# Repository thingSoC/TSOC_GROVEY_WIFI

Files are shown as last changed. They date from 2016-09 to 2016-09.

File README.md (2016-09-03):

# TSOC-GROVEY_WIFI

**TSOC-GROVEY_WIFI** is a Wi-Fi Embedded Module, **thingSoC Reference Design.** 

**thingSoC Reference Designs** are example thingSoC implementations that implement
various reference and testing circuits for demonstrating the use of the thingSoC libraries.
These reference designs are complete designs and can also serve as starting templates for users to customize.

**TSOC-GROVEY_WIFI** includes an ESP8266-07/12E format Wi-Fi module, in a thingSoC compatible pinout.

---------------------------------------

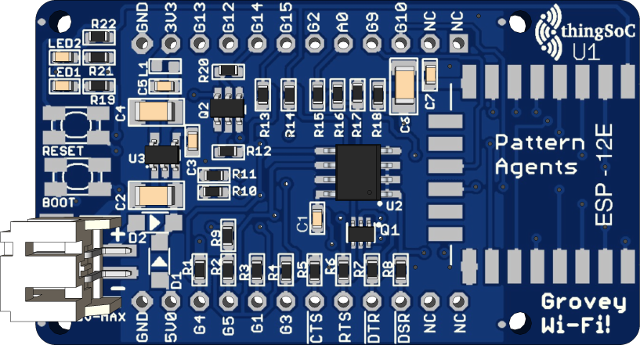
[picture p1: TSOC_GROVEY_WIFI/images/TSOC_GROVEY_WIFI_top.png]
thingSoC TSOC-GROVEY_WIFI
[  
*TSOC-GROVEY_WIFI*](https://github.com/thingSoC/thingSoC/tree/master/examples/eagle6/TSOC-GROVEY_WIFI)

* [Supported by the Arduino IDE](https://www.arduino.cc/) 
* Wi-Fi and OTA (Over the Air) Program Upgrade/Download
* thingSoC Compliant Module
* [Mikrobus Compatible Module](http://www.mikroe.com/mikrobus/) 
* ESP8266 Wi-Fi Module 802.11 b/g/n
* +19.5dBm output power in 802.11b mode
* Wi-Fi Direct (P2P), soft-AP
* Integrated TCP/IP protocol stack
* Internal Antenna and U.FL external Antenna Support

---------------------------------------

## Documentation Index <a name="documentation_index"/>

For ESP8266 Documentation (esp. toolchain info) see [NurdSpace](https://nurdspace.nl/ESP8266)

[thingSoC Organization Website](http://thingSoC.github.io)

[thingSoC FAQ - Frequently Asked Questions](http://thingsoc.github.io/support/faq.html)

---------------------------------------

[  
*thingSoC*](http://thingsoc.github.io)

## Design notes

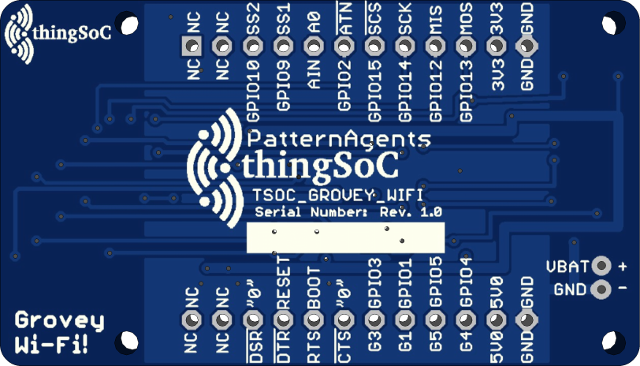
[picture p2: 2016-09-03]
TSOC_GROVEY_WIFI/images/TSOC_GROVEY_WIFI_bot.png

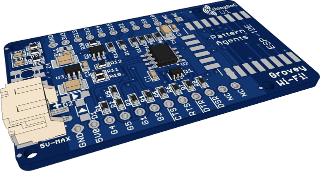
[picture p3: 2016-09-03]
TSOC_GROVEY_WIFI/images/TSOC_GROVEY_WIFI_model.png

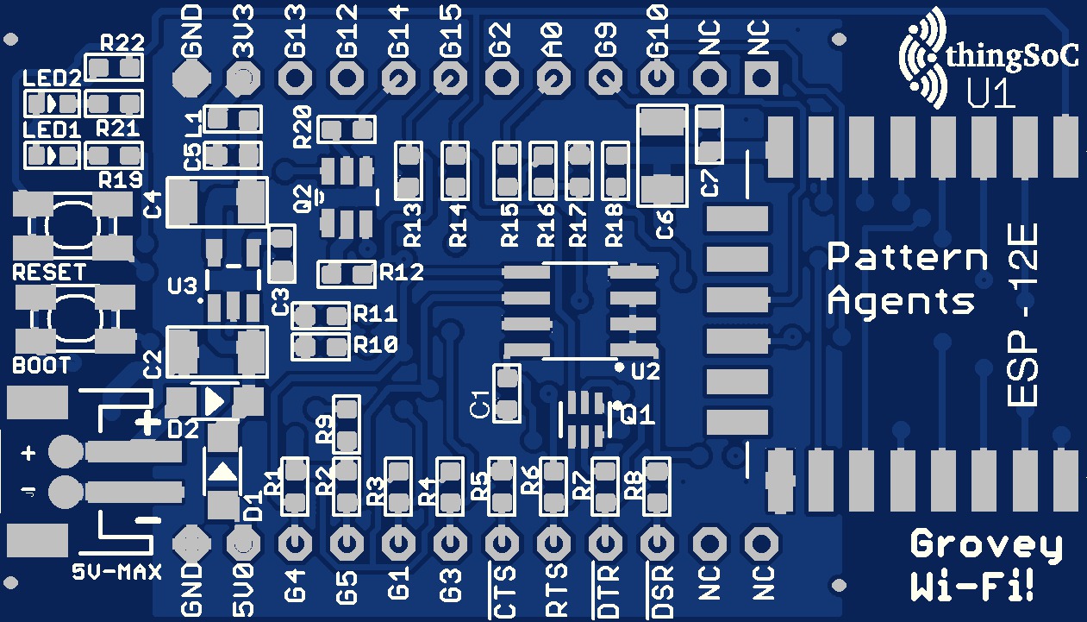
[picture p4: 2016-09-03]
TSOC_GROVEY_WIFI/eagleUp/eagleUp_TSOC_GROVEY_WIFI_board_top.jpg

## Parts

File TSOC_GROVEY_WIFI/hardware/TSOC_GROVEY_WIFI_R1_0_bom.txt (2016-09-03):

Partlist exported from U:/PatternAgents/eagle/TSOC_Modules/TSOC_GROVEY_WIFI/TSOC_GROVEY_WIFI/TSOC_GROVEY_WIFI.sch at 8/28/2016 3:01:39 PM

Qty Value             Device                                 Package               Parts                          Description                          
1                     ESP12ESMD                              ESP12E-SMD            U1                             ESP12E Module                        
1                     JST_2MM_MALE                           JST-2-SMD             J1                             Mates to single-cell LiPo batteries. 
1                     M02-JST-2-PTH-NO_SILK                  JST-2-PTH-NS          J1P                            Standard 2-pin 0.1" header. Use with 
3   100K              SMD-RES-100K-1%-1/10W(0603)            R0603                 R15, R16, R17                  301010196                            
2   100K 1/10W        SMD-RES-100K-5%-1/10W(0603)            R0603                 R5, R8                         301010089                            
3   100nf             CERAMIC-100NF-50V-10%-X7R(0603)        C0603                 C1, C5, C7                     302010138                            
7   10K               SMD-RES-10K-1%-1/10W(0603)             R0603                 R6, R7, R9, R13, R14, R18, R22 301010299                            
3   10uf              CERAMIC-10UF-25V-10%-X5R(1206)         C1206                 C2, C4, C6                     302010181                            
4   1K 1/10W          SMD-RES-1K-5%-1/10W(0603)              R0603                 R10, R11, R19, R21             301010291                            
6   2.2K              SMD-RES-2.2K-5%-1/10W(0603)            R0603                 R1, R2, R3, R4, R12, R20       301010124                            
2   20V-1A            SMD-DIODE-SCHOTTKY-20V-1A(SOD-123)     SOD-123               D1, D2                         304020034                            
1   470pF             CERAMIC-100NF-50V-10%-X7R(0603)        C0603                 C3                             302010138                            
2   DHT-4235A         SMD-BUTTON-TOP-DHT-4235A(4P-4.2X3.2MM) SW4-SMD-4.2X3.2X2.5MM BOOT, RESET                    311020045                            
1   DNP               SMD-FERRITE-CHIP-120-OHM-500MA(0603)   L0603                 L1                             303030001                            
1   FDG1024NZ         FDG1024NZ                              SOT95P280X110-6N      Q2                             FDG1024NZ                            
4   FIDUCIALUFIDUCIAL FIDUCIALUFIDUCIAL                      MICRO-FIDUCIAL        FID1, FID2, FID3, FID4         Fiducial Alignment Points            
1   FM24W256-G        FM24W256-G                             SO08                  U2                             I2C FRAM FM24W256                    
1   GREEN-0603        SMD-LED-CLEAR-GREEN(0603)              LED-0603              LED1                           304090043                            
1   MIC5219 3.3V      V_REG_MIC52193.3V                      SOT23-5               U3                             V_REG MIC5219                        
1   MMBT2222A         MMDT3904                               SOT363                Q1                             Dual NPN transistor                  
1   RED-0603          LED-SMD-RED-DIFFUSED(0603)             LED-0603              LED2                           304090042                            
1   TSOC-24-BB        TSOC-24-BB                             TSOC-BB-S24           TSOC                           thingSoC Twenty-Four(24) Pin Socket  
4   TSOC-LOGO-MED     TSOC-LOGO-MED                          TSOC-LOGO-MED         $$U$1, $$U$2, U$101, U$102     thingSoC Logo                        
1   TSOC-PCB-PLUS     TSOC-PCB-PLUS                          TSOC-BB-BRD-PLUS-DIM  PCB                            thingSoC PCB Outlines

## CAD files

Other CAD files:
TSOC_GROVEY_WIFI/eagleUp/TSOC_GROVEY_WIFI.skp

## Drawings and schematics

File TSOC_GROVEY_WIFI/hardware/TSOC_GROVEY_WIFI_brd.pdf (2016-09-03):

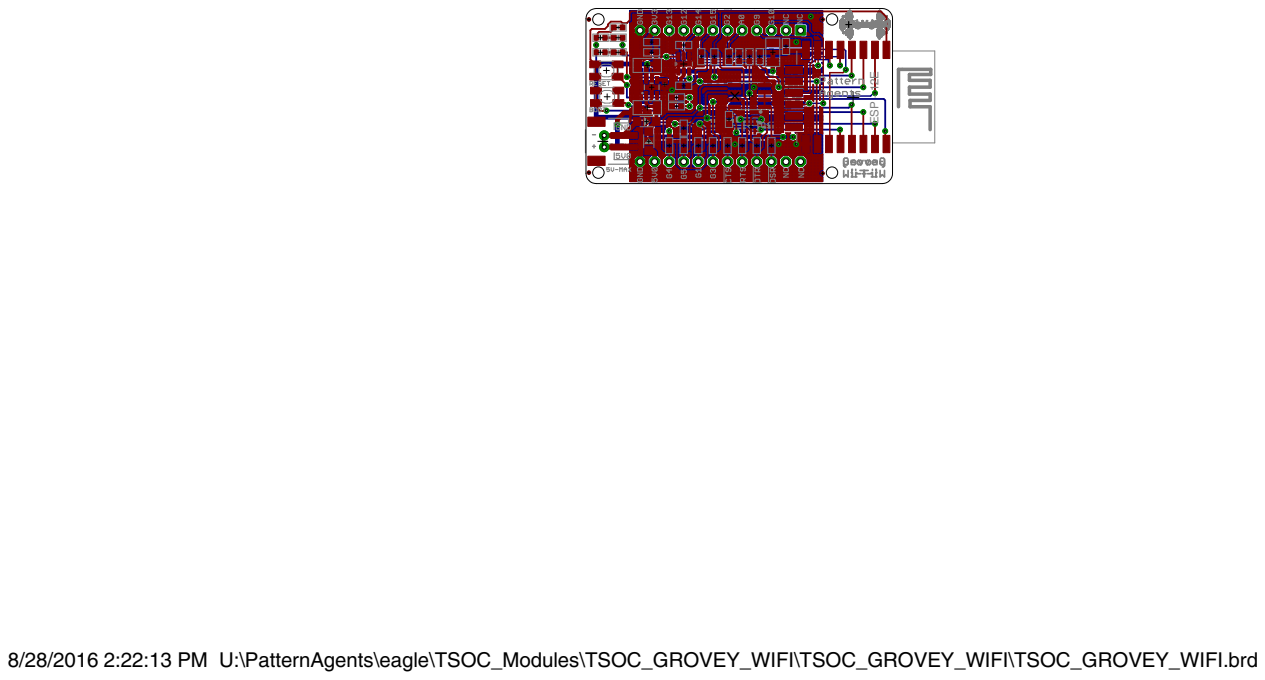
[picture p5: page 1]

8/28/2016 2:22:13 PM U:\PatternAgents\eagle\TSOC_Modules\TSOC_GROVEY_WIFI\TSOC_GROVEY_WIFI\TSOC_GROVEY_WIFI.brd

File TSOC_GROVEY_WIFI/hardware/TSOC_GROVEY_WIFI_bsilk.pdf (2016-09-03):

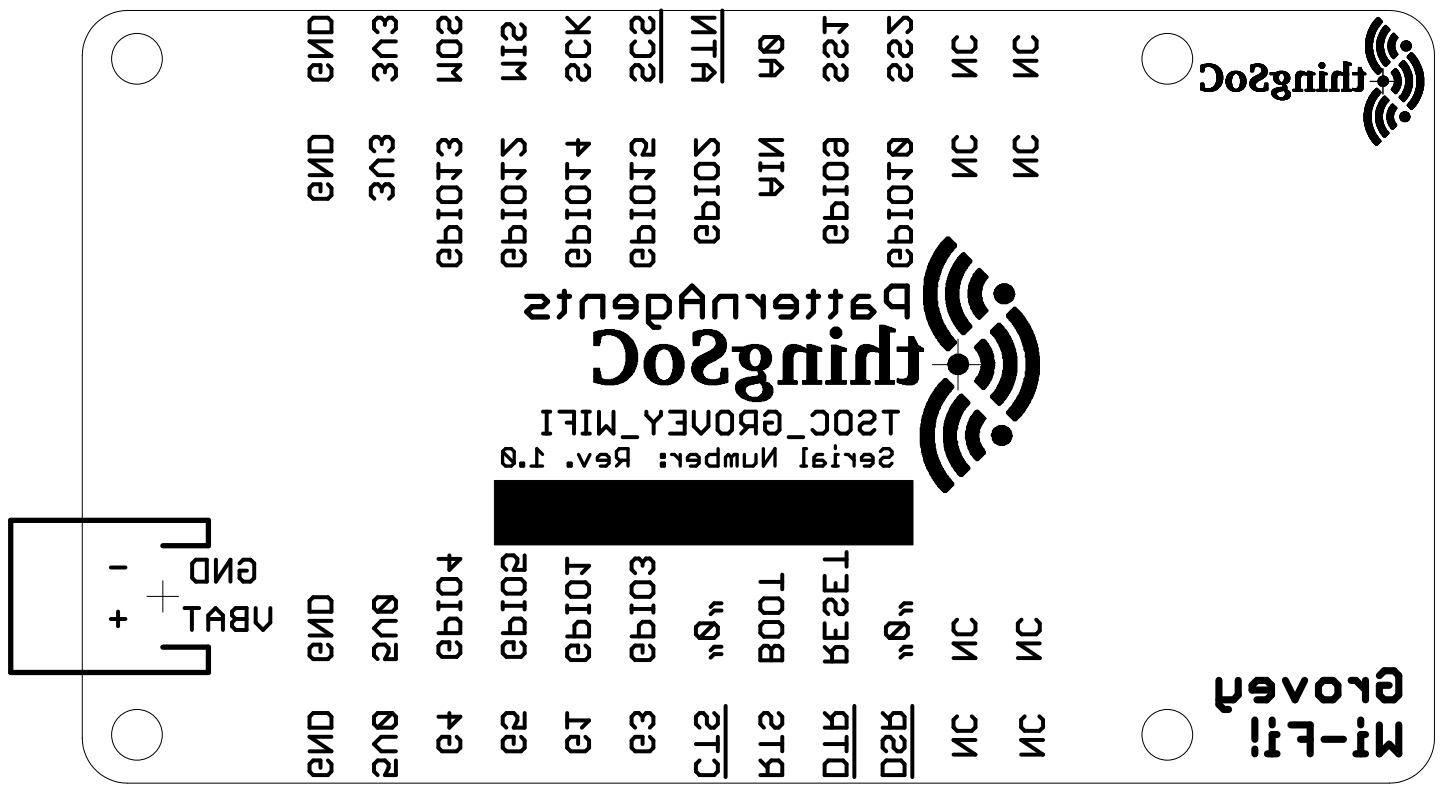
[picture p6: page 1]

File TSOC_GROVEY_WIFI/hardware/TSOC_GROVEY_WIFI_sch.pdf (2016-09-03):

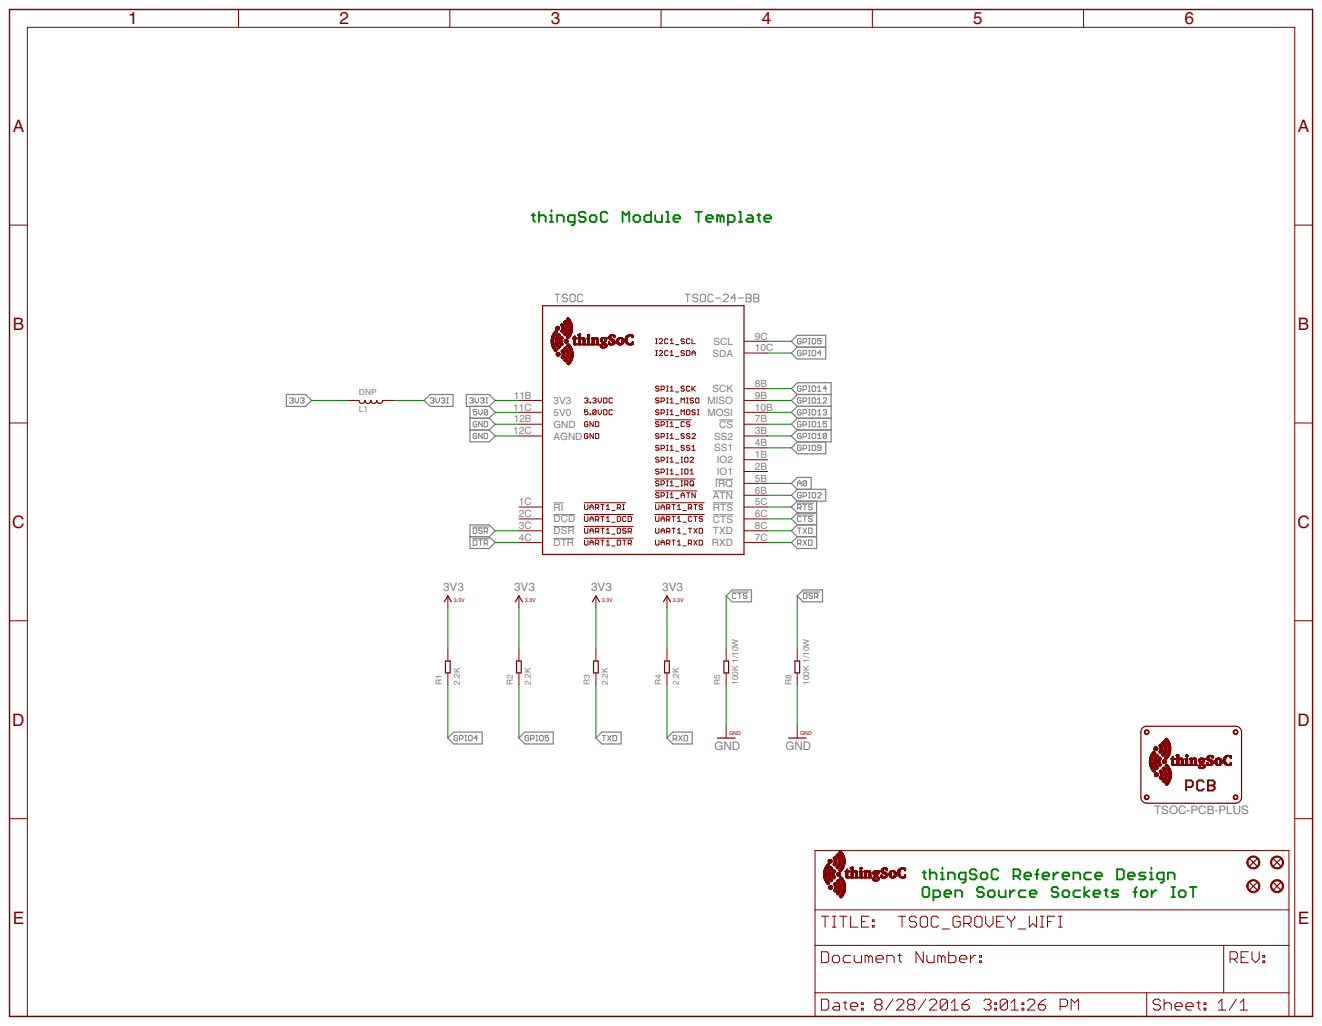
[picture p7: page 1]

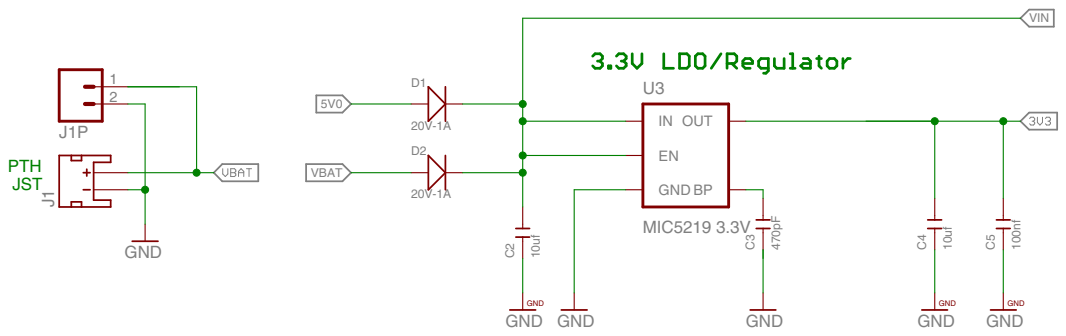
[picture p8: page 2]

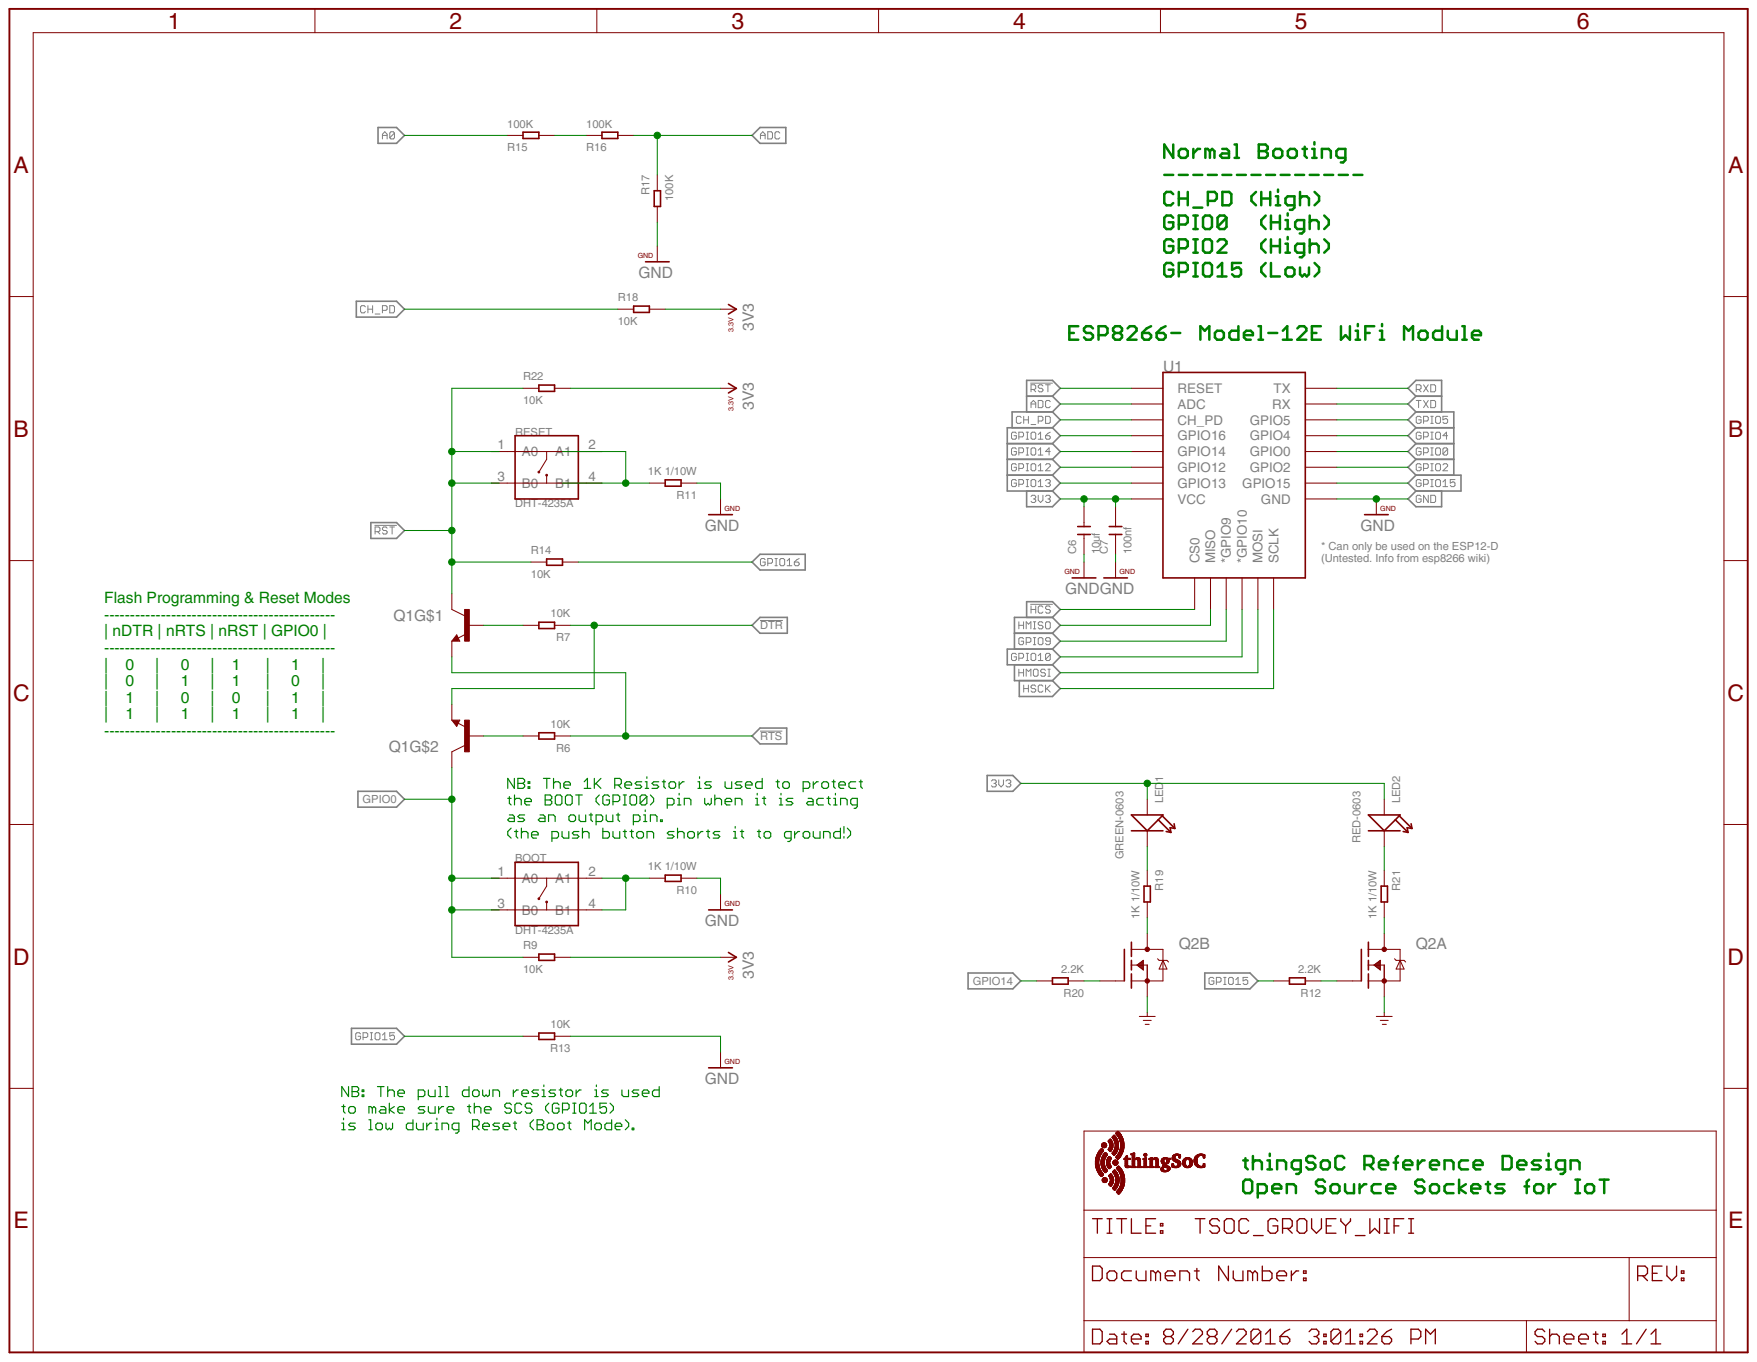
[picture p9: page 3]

* Can only be used on the ESP12-D
(Untested. Info from esp8266 wiki)

Flash Programming & Reset Modes
nDTR | nRTS | nRST | GPIO0 | ---------------------------------------------

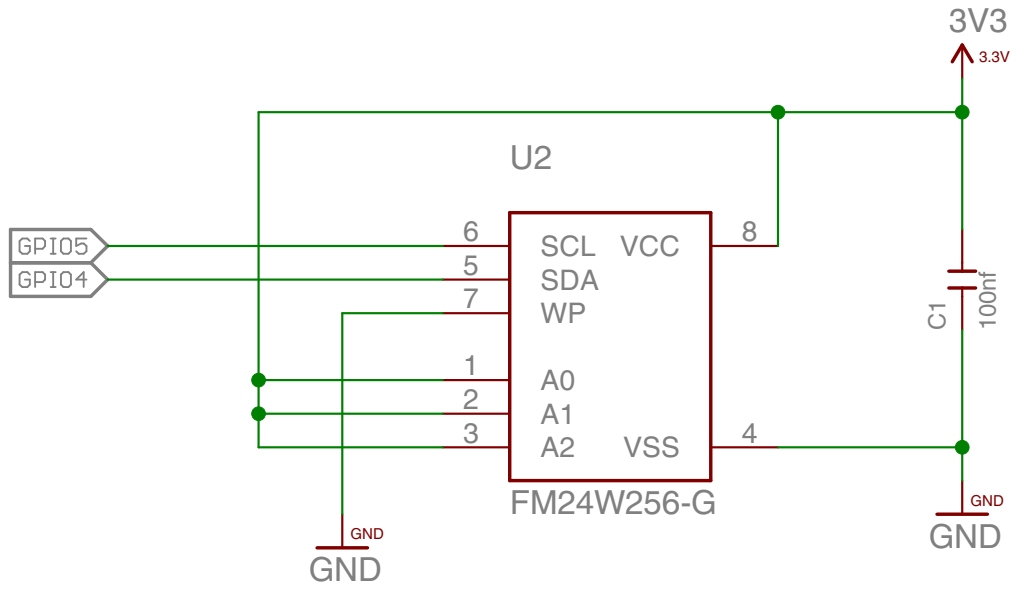
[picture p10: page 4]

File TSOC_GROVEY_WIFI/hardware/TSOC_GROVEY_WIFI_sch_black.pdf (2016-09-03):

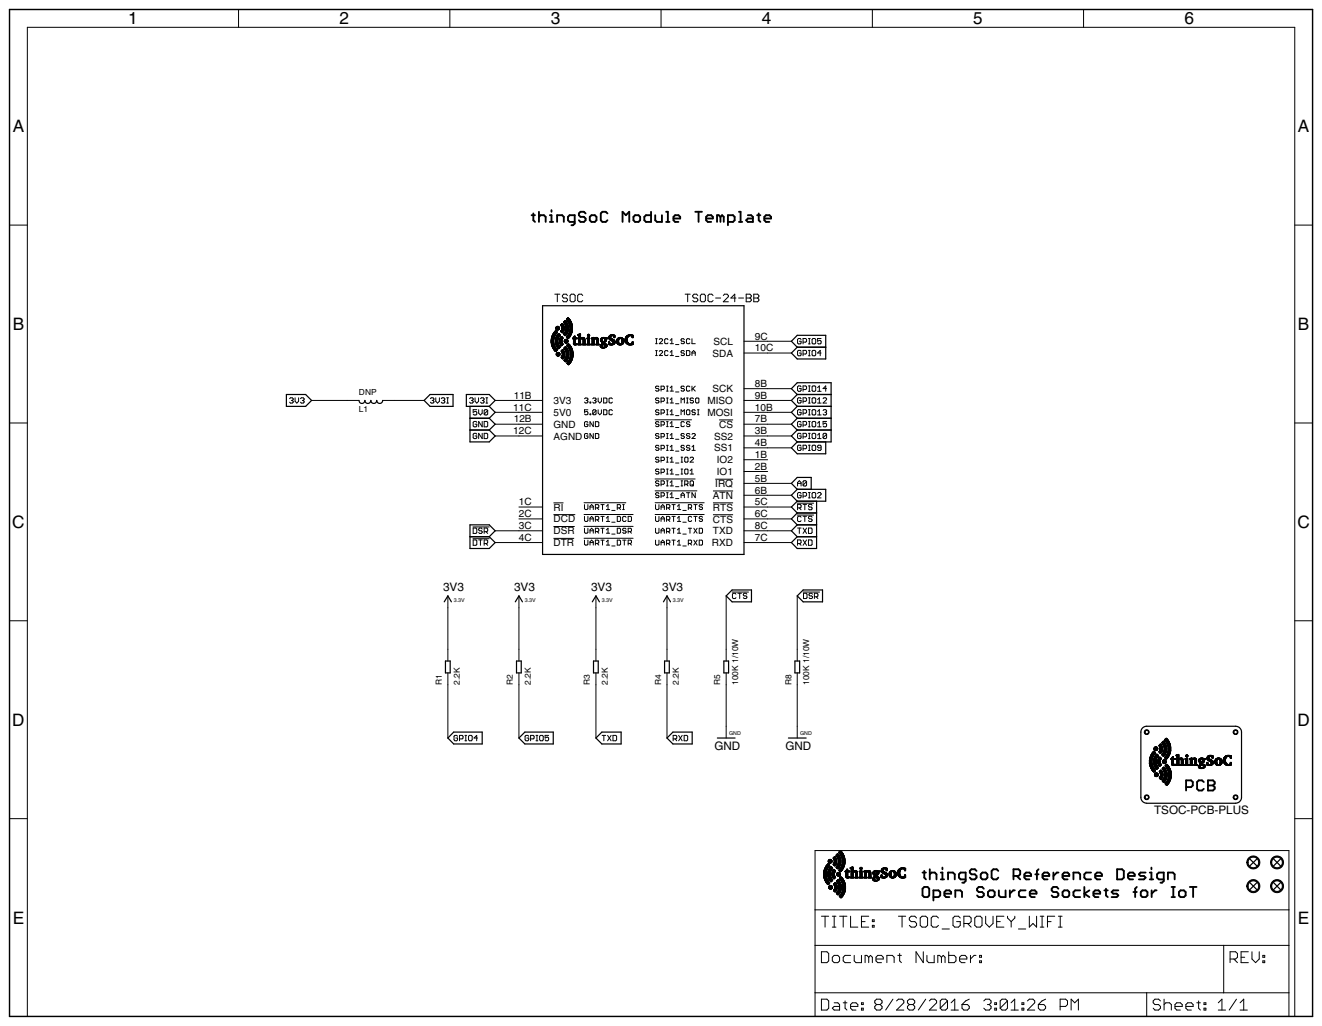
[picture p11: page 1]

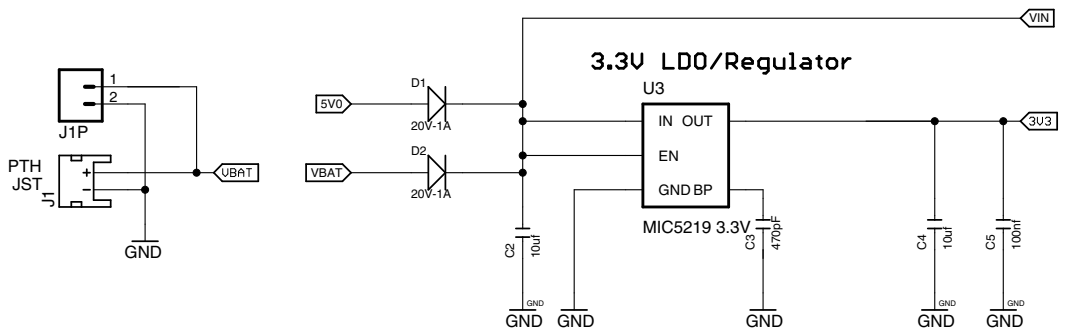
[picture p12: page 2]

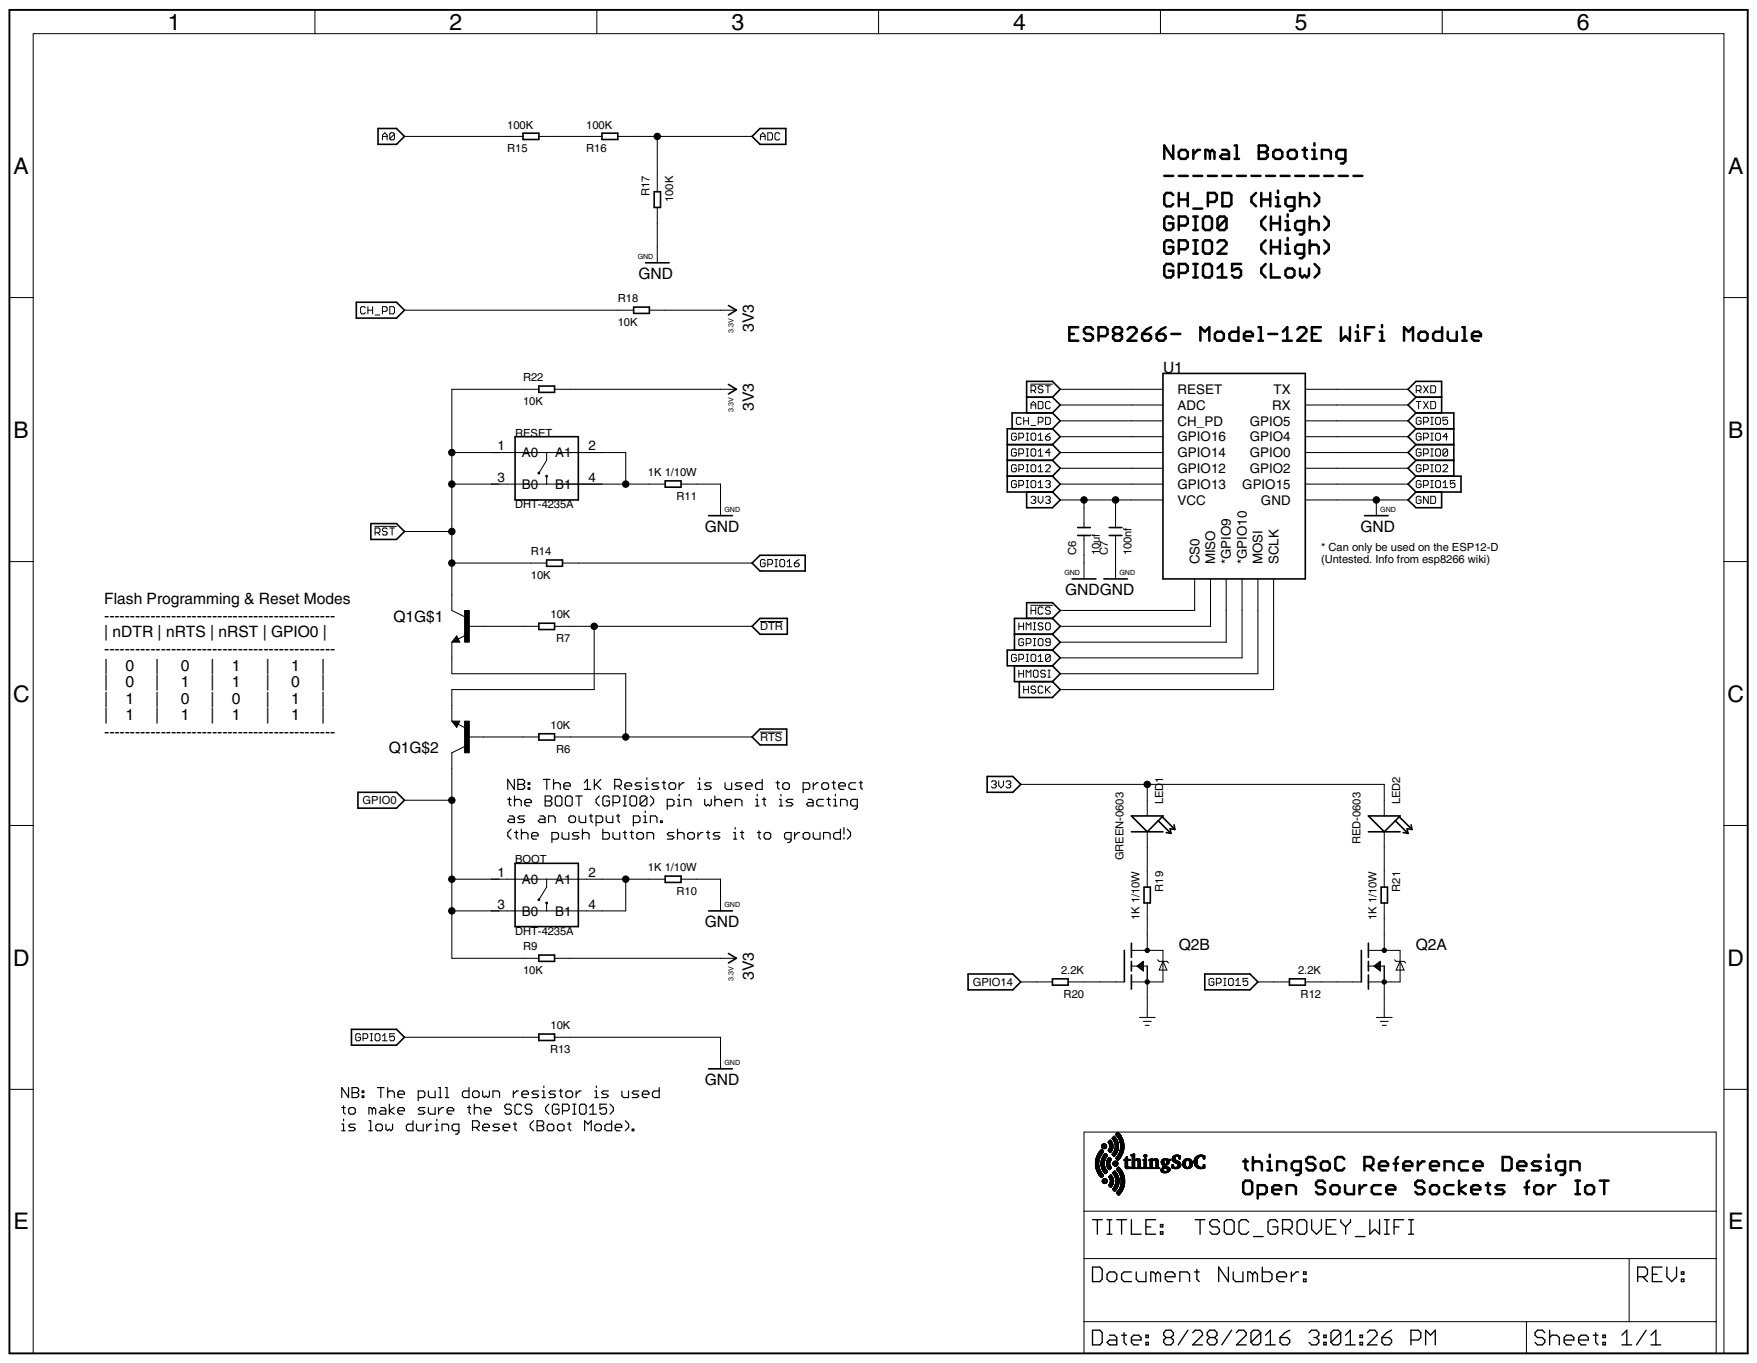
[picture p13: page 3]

* Can only be used on the ESP12-D
(Untested. Info from esp8266 wiki)

Flash Programming & Reset Modes
nDTR | nRTS | nRST | GPIO0 | ---------------------------------------------

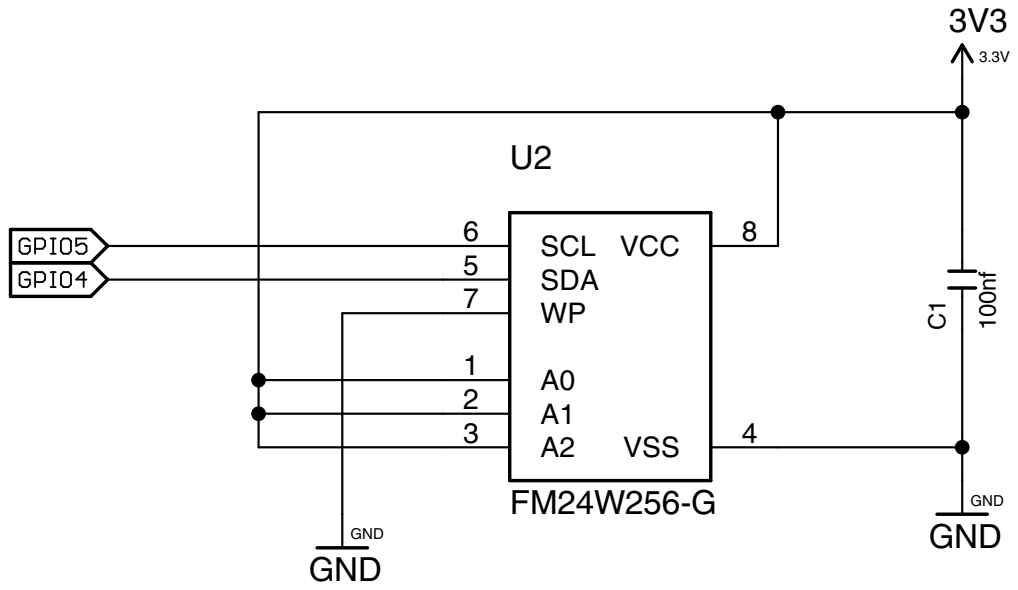
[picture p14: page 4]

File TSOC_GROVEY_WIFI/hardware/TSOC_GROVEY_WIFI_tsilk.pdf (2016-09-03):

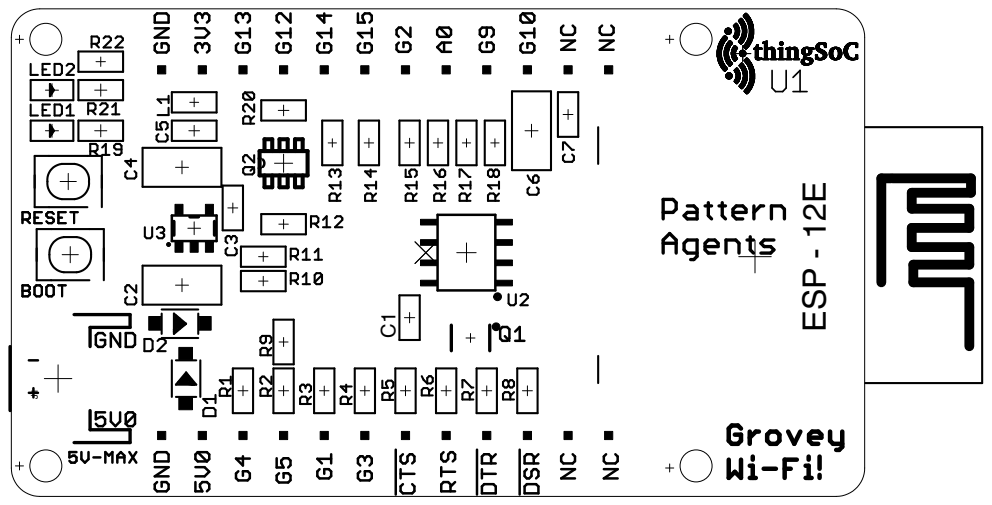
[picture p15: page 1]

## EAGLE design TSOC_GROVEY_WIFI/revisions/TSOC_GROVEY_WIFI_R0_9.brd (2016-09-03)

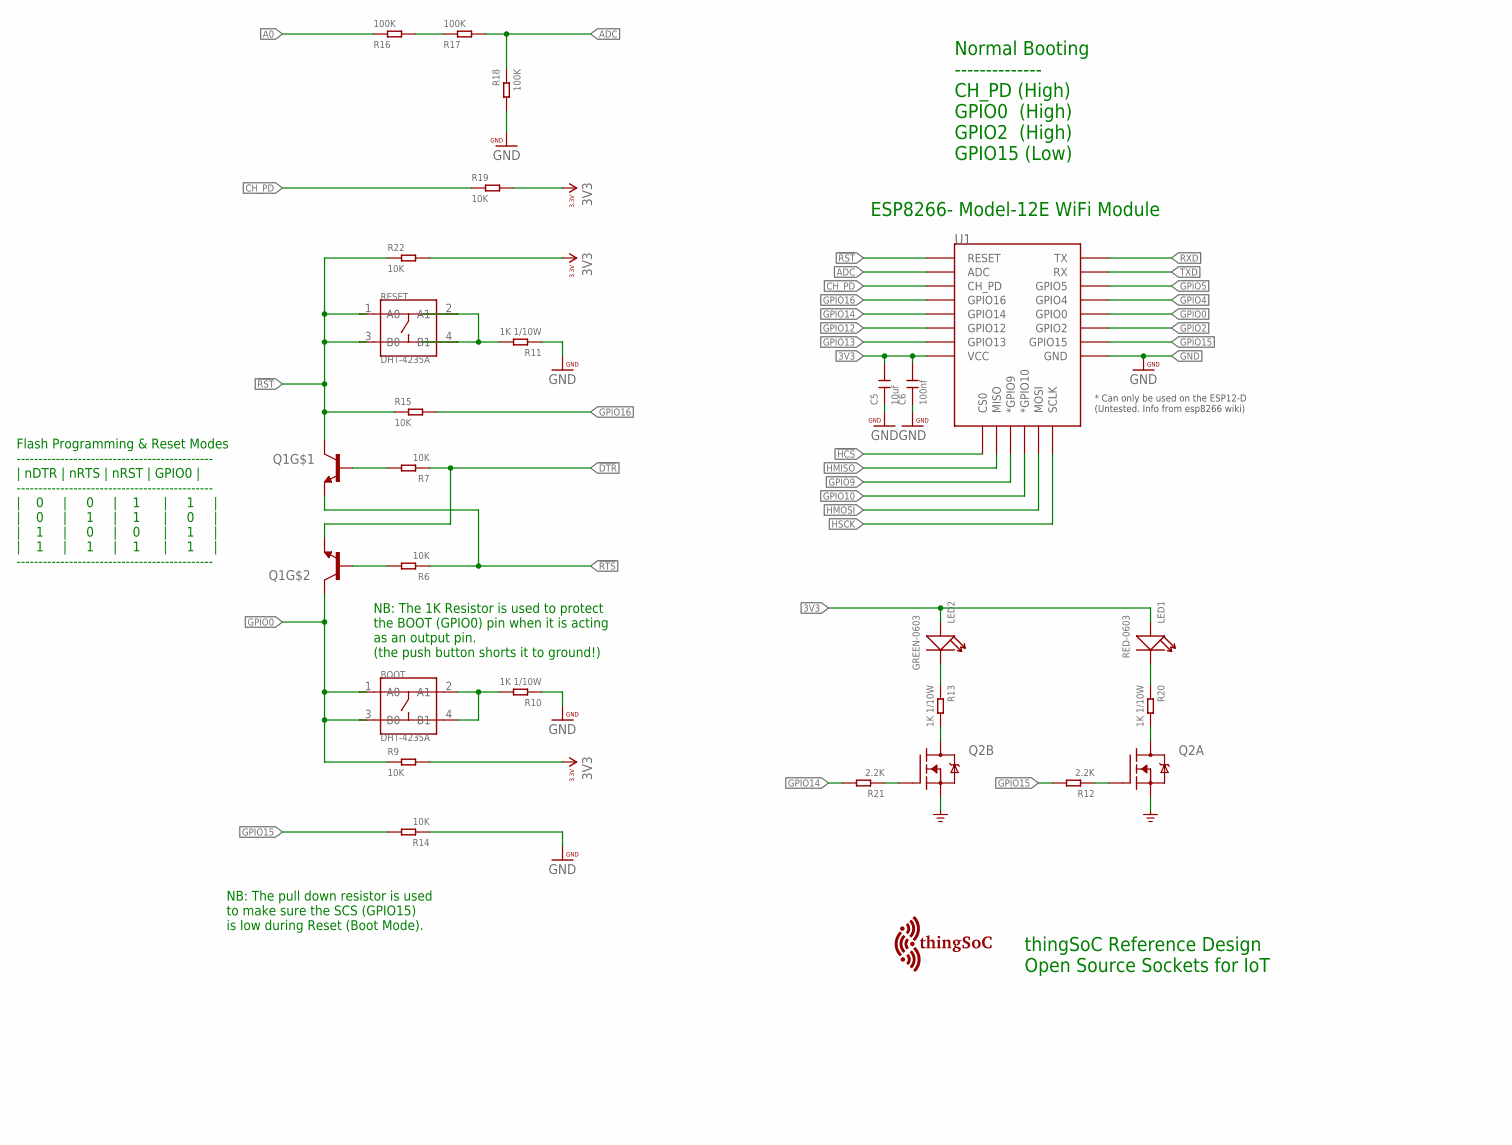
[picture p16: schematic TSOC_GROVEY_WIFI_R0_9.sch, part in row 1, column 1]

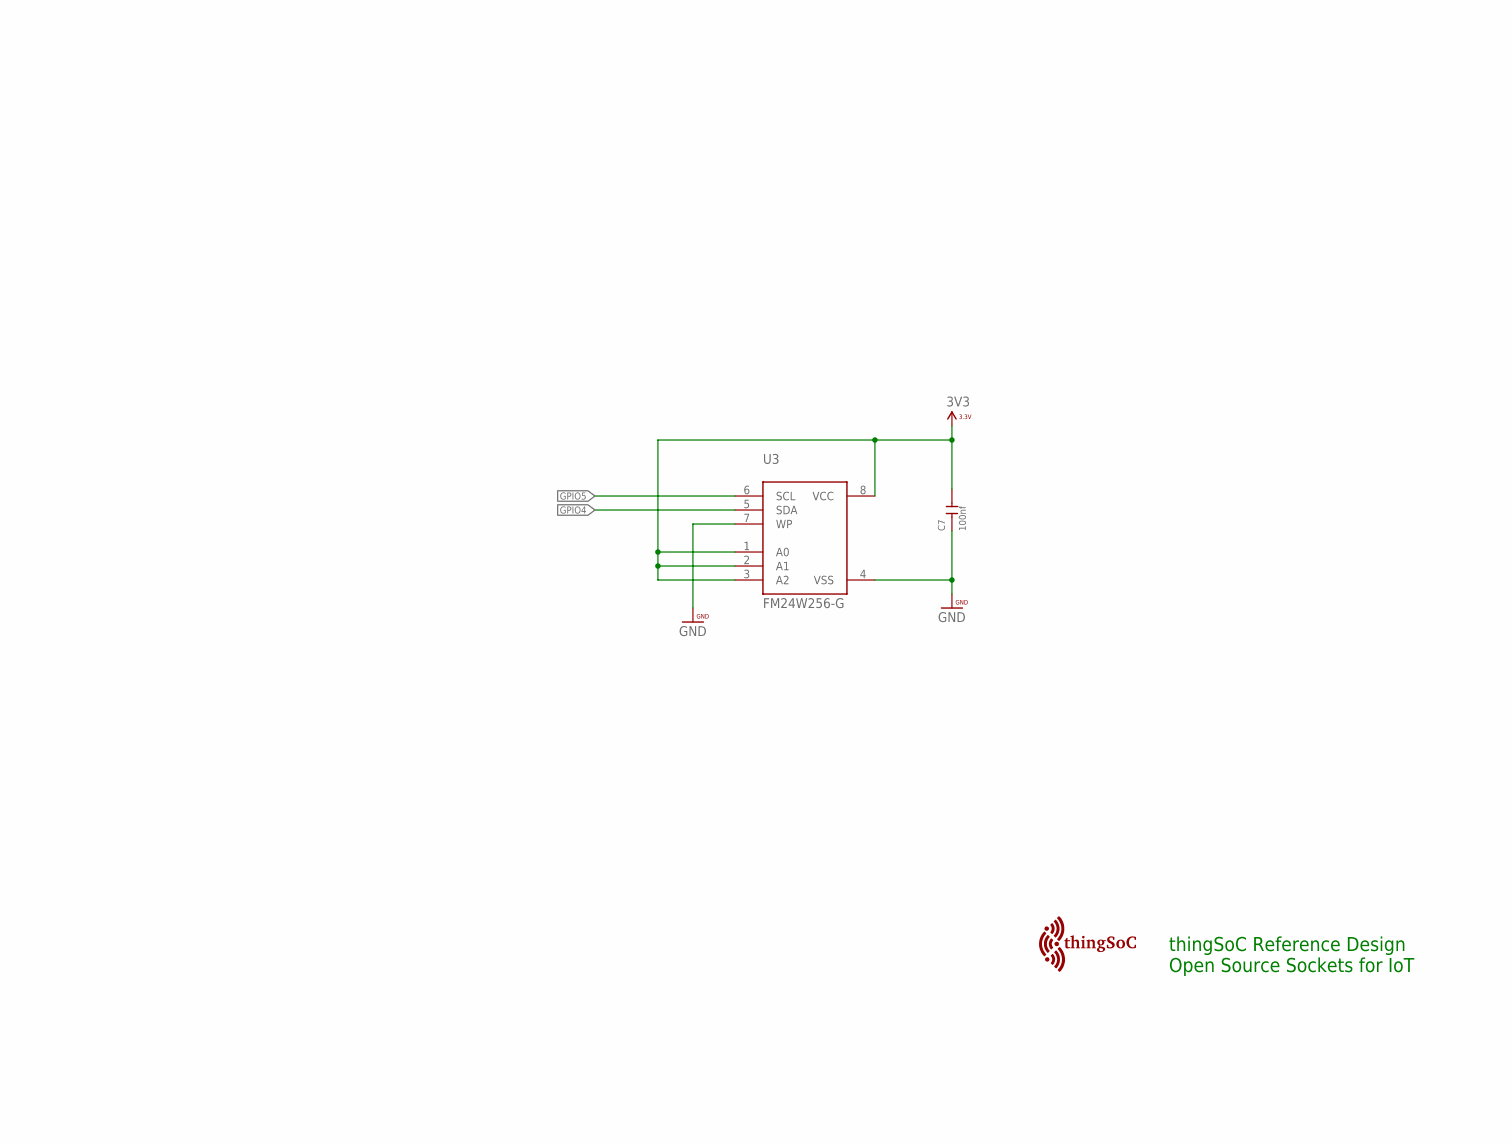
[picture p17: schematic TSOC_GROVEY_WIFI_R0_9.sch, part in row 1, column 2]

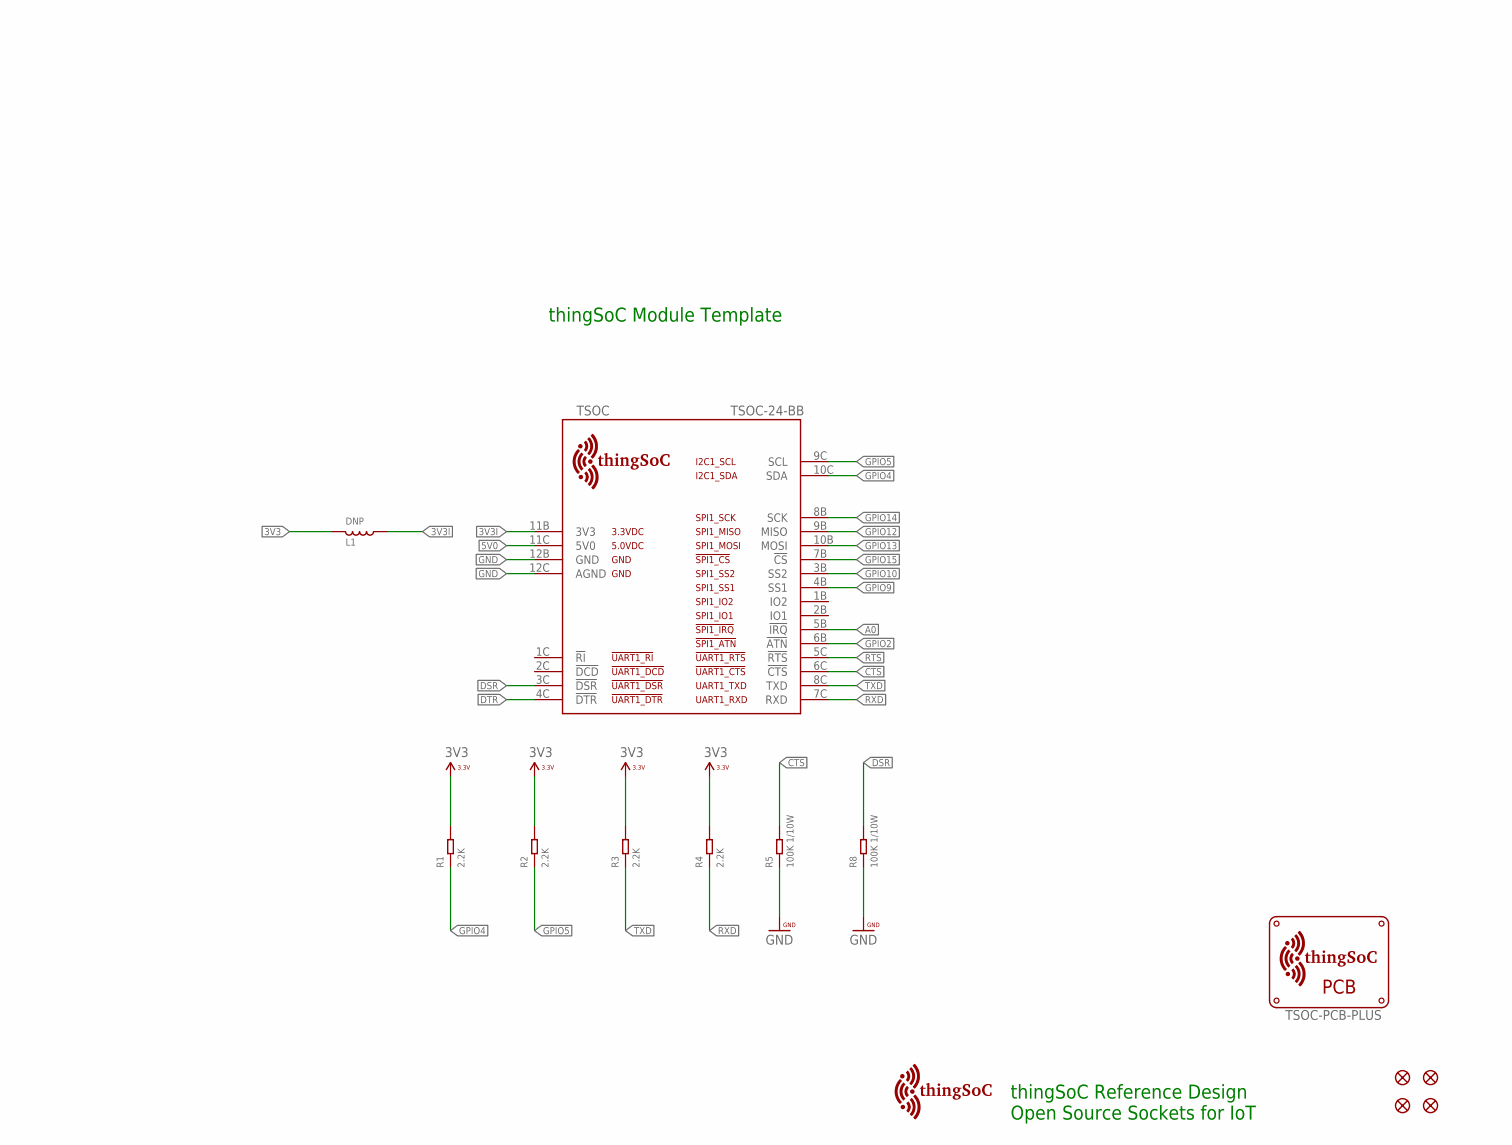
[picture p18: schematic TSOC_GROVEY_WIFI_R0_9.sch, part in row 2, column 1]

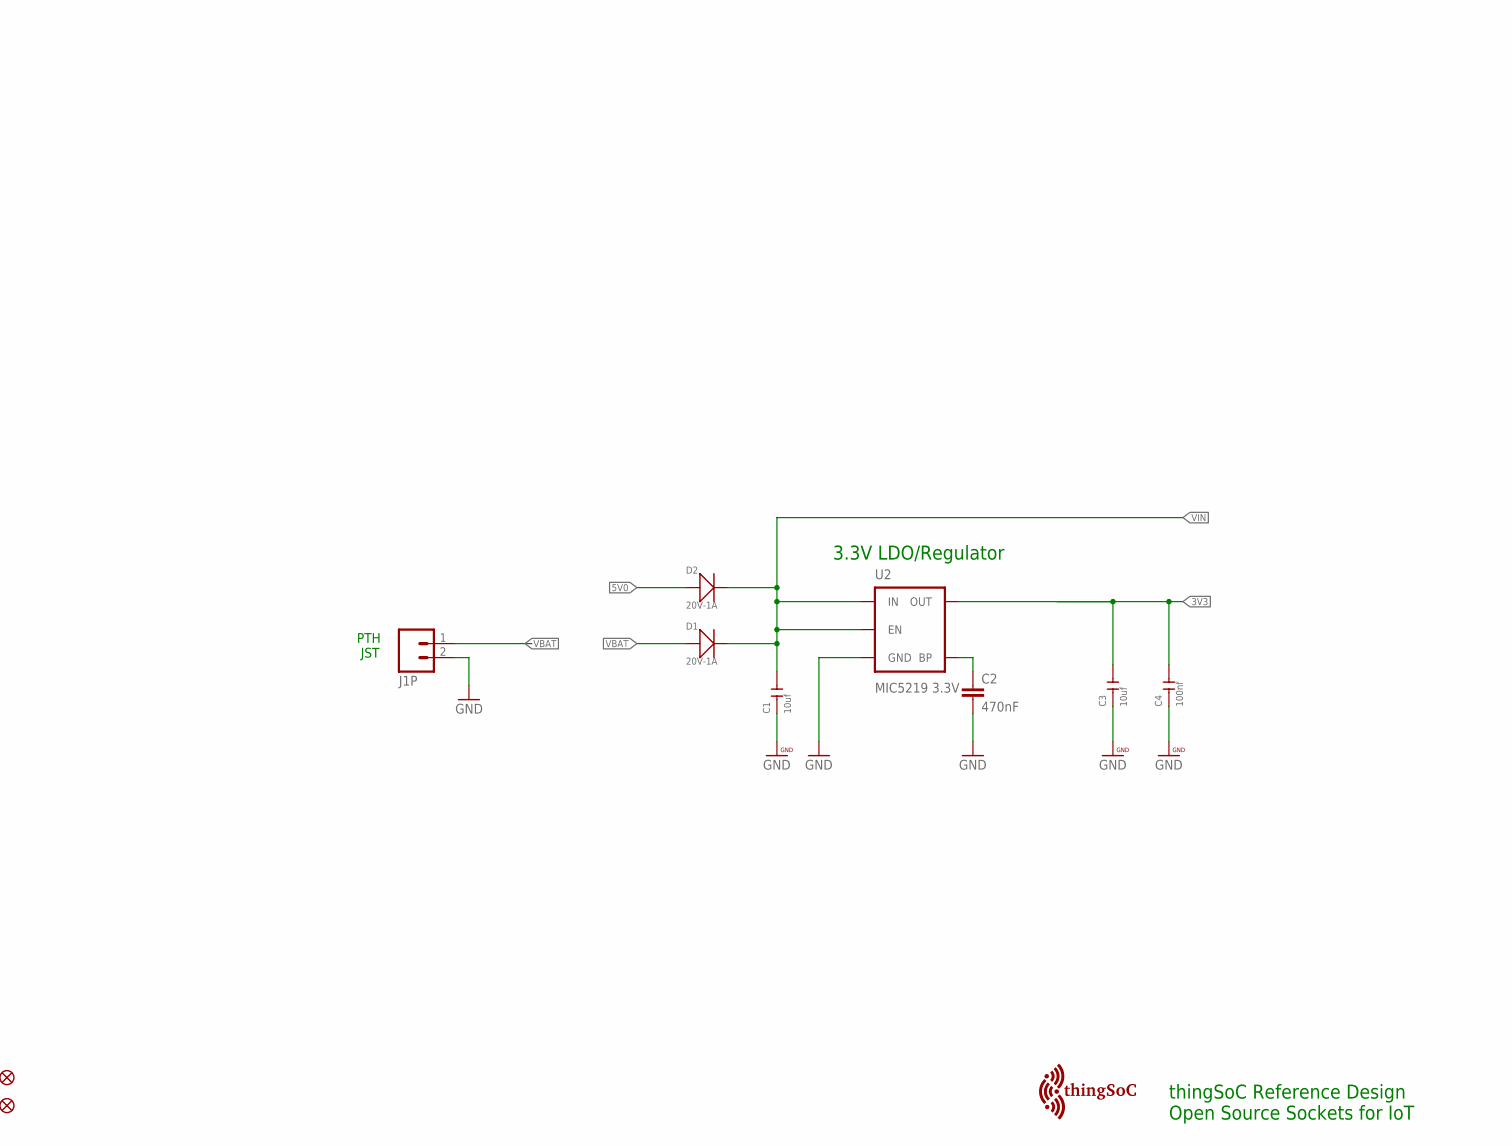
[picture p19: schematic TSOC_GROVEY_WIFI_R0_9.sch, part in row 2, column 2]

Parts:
BOOT: DHT-4235A; SW4-SMD-4.2X3.2X2.5MM
C1, C3, C5: 10uf; C1206
C2: 470nF; 0402-CAP
C4, C6, C7: 100nf; C0603
D1, D2: 20V-1A; SOD-123
FID1, FID2, FID3, FID4: FIDUCIALUFIDUCIAL; MICRO-FIDUCIAL
J1P: M02-JST-2-PTH-NO_SILK; JST-2-PTH-NS
L1: DNP; L0603
LED1: RED-0603; LED-0603
LED2: GREEN-0603; LED-0603
PCB: TSOC-PCB-PLUS; TSOC-BB-BRD-PLUS-DIM
Q1: MMBT2222A; SOT363
Q2: FDG1024NZ; SOT95P280X110-6N
R1, R2, R3, R4, R12, R21: 2.2K; R0603
R5, R8: 100K 1/10W; R0603
R6, R7, R9, R14, R15, R19, R22: 10K; R0603
R10, R11, R13, R20: 1K 1/10W; R0603
R16, R17, R18: 100K; R0603
RESET: DHT-4235A; SW4-SMD-4.2X3.2X2.5MM
TSOC: TSOC-24-BB; TSOC-BB-S24
U1: ESP12ESMD; ESP12E-SMD
U2: MIC5219 3.3V; SOT23-5
U3: FM24W256-G; SO08
U$22, U$23, U$26, U$28: TSOC-LOGO-MED

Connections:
3V3: C3.2, C4.2, C5.2, C6.2, C7.2, L1.1, LED1.+, LED2.+, R1.2, R2.2, R3.2, R4.2, R9.2, R19.2, R22.2, U1.VCC, U2.5 (OUT), U3.1 (A0), U3.2 (A1), U3.3 (A2), U3.8 (VCC)
3V3I: L1.2, TSOC.11B (3V3)
5V0: D2.+, TSOC.11C (5V0)
!BOOTPD: BOOT.2 (A1), BOOT.4 (B1), R10.2
!CTS: R5.2, TSOC.6C (!CTS)
!DCDG: Q2.2 (G), R12.1
!DSR: R8.2, TSOC.3C (!DSR)
!DTR: Q1.1 (E), R7.1, TSOC.4C (!DTR)
!HCS: U1.CS0
!RST: Q1.3 (C), R15.1, R22.1, RESET.1 (A0), RESET.3 (B0), U1.RESET
!RSTPD: R11.2, RESET.2 (A1), RESET.4 (B1)
!RTS: Q1.4 (E), R6.1, TSOC.5C (!RTS)
!SCSG: Q2.5 (G), R21.1
A0: R16.1, TSOC.5B (!IRQ)
ADC: R17.2, R18.1, U1.ADC
ADC2: R16.2, R17.1
BYPASS1: C2.1, U2.4 (BP)
CH_PD: R19.1, U1.CH_PD
G0: Q2.6 (D), R20.2
G15: Q2.3 (D), R13.2
GND: C1.1, C2.2, C3.1, C4.1, C5.1, C6.1, C7.1, J1P.2, Q2.1 (S), Q2.4 (S), R5.1, R8.1, R10.1, R11.1, R14.1, R18.2, TSOC.12B (GND), TSOC.12C (AGND), U1.GND, U2.2 (GND), U3.4 (VSS), U3.7 (WP)
GPIO0: BOOT.1 (A0), BOOT.3 (B0), Q1.6 (C), R9.1, U1.GPIO0
GPIO2: TSOC.6B (!ATN), U1.GPIO2
GPIO4: R1.1, TSOC.10C (SDA), U1.GPIO4, U3.5 (SDA)
GPIO5: R2.1, TSOC.9C (SCL), U1.GPIO5, U3.6 (SCL)
GPIO9: TSOC.4B (SS1), U1.GPIO9 (*GPIO9)
GPIO10: TSOC.3B (SS2), U1.GPIO10 (*GPIO10)
GPIO12: TSOC.9B (MISO), U1.GPIO12
GPIO13: TSOC.10B (MOSI), U1.GPIO13
GPIO14: R21.2, TSOC.8B (SCK), U1.GPIO14
GPIO15: R12.2, R14.2, TSOC.7B (!CS), U1.GPIO15
GPIO16: R15.2, U1.GPIO16
HMISO: U1.MISO
HMOSI: U1.MOSI
HSCK: U1.SCLK
LED1: LED2.-, R13.1
LED2: LED1.-, R20.1
RES: Q1.5 (B), R7.2
ROS: Q1.2 (B), R6.2
RXD: R4.1, TSOC.7C (RXD), U1.TXD0 (TX)
TXD: R3.1, TSOC.8C (TXD), U1.RXD0 (RX)
VBAT: D1.+, J1P.1
VIN: C1.2, D1.-, D2.-, U2.1 (IN), U2.3 (EN)

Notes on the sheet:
thingSoC Reference Design Open Source Sockets for IoT
thingSoC Module Template
Normal Booting -------------- CH_PD (High) GPIO0 (High) GPIO2 (High) GPIO15 (Low)
ESP8266- Model-12E WiFi Module
Flash Programming & Reset Modes --------------------------------------------- | nDTR | nRTS | nRST | GPIO0 | --------------------------------------------- | 0 | 0 | 1 | 1 | | 0 | 1 | 1 | 0 | | 1 | 0 | 0 | 1 | | 1 | 1 | 1 | 1 | ---------------------------------------------
NB: The 1K Resistor is used to protect the BOOT (GPIO0) pin when it is acting as an output pin. (the push button shorts it to ground!)
NB: The pull down resistor is used to make sure the SCS (GPIO15) is low during Reset (Boot Mode).
PTH JST
3.3V LDO/Regulator

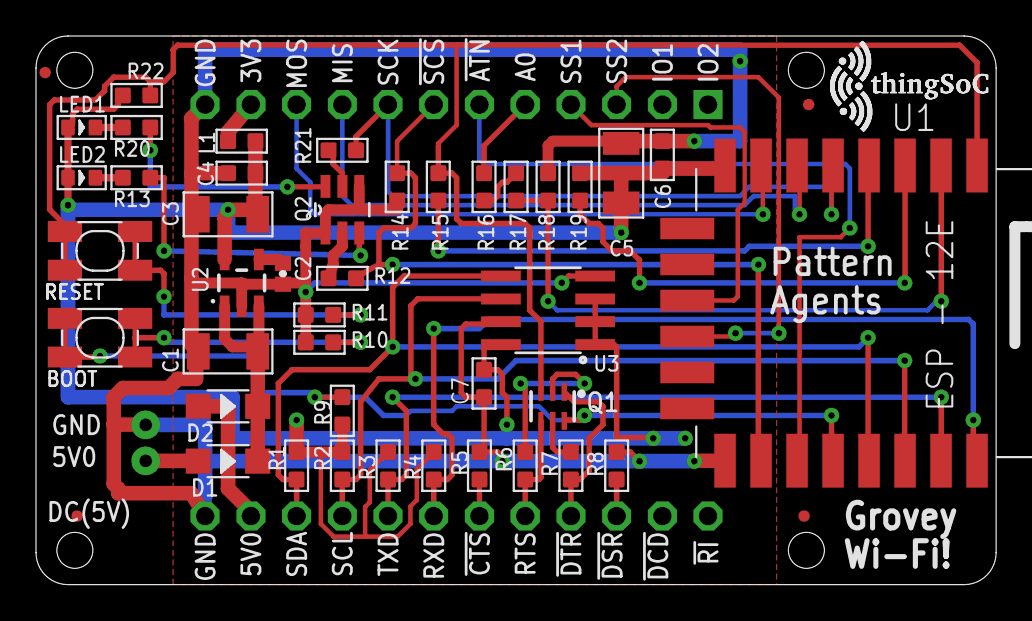
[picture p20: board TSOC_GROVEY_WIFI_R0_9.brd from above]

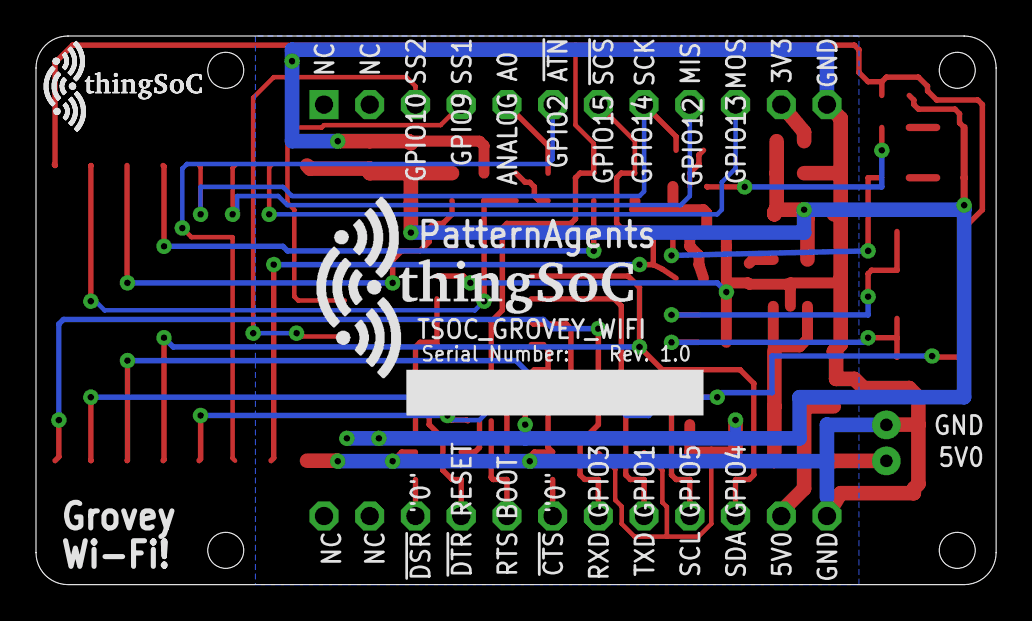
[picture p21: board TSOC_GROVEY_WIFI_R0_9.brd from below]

Board: 2 copper layers, 53.3 x 30.5 mm, 53 parts (3 on the bottom side), 39 nets.

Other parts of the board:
U$101: TSOC-LOGO-LRG

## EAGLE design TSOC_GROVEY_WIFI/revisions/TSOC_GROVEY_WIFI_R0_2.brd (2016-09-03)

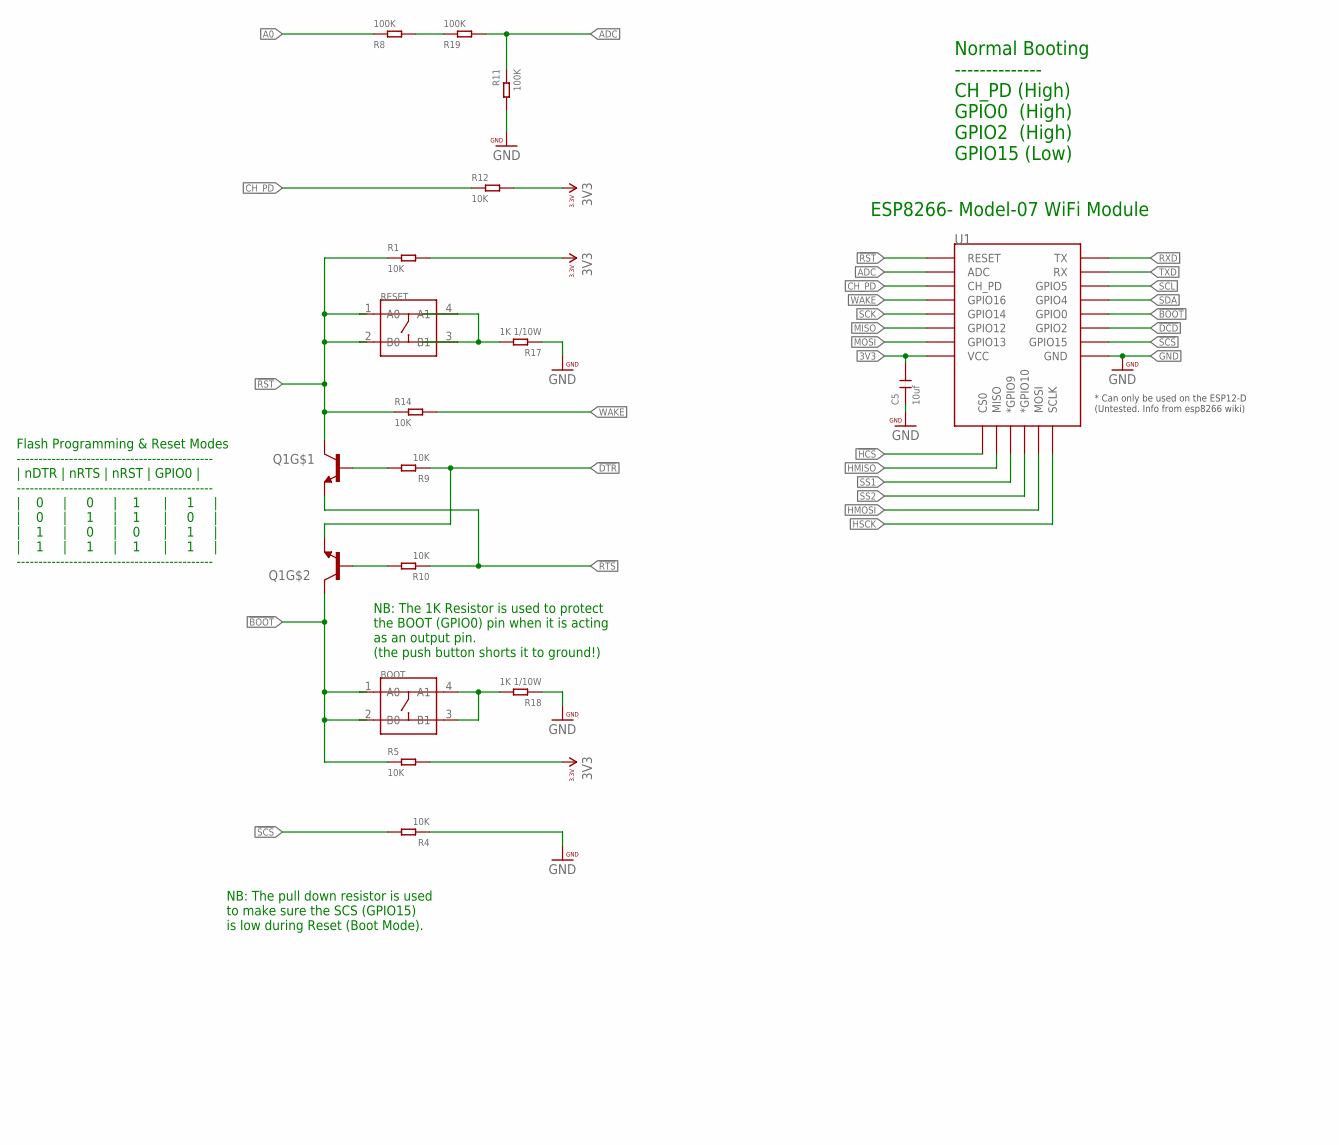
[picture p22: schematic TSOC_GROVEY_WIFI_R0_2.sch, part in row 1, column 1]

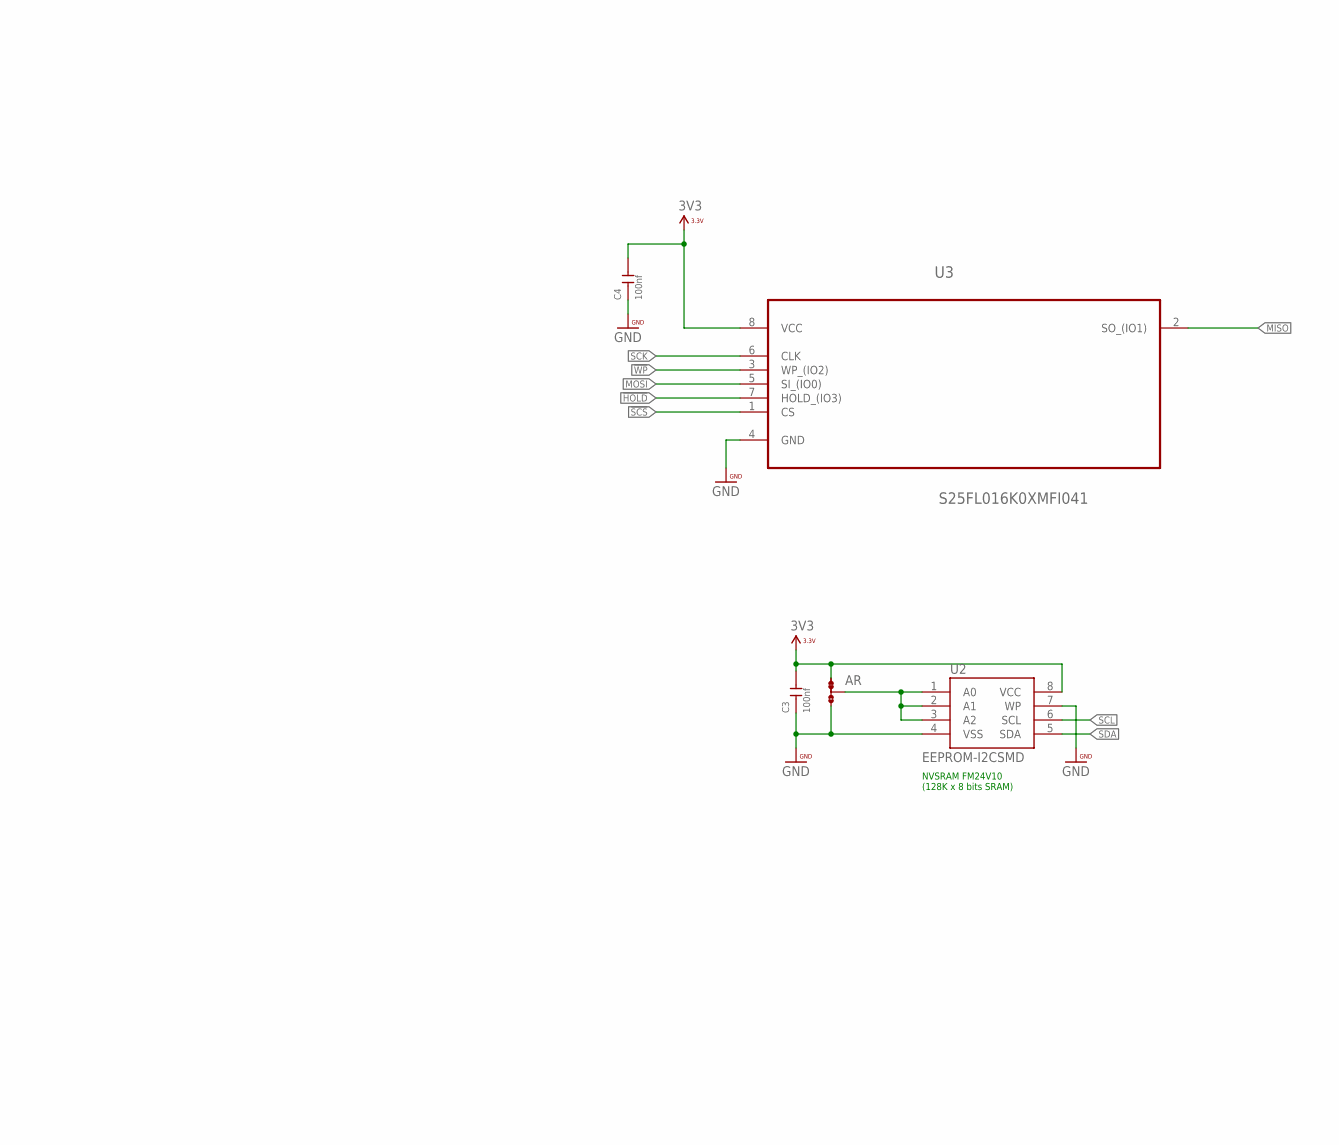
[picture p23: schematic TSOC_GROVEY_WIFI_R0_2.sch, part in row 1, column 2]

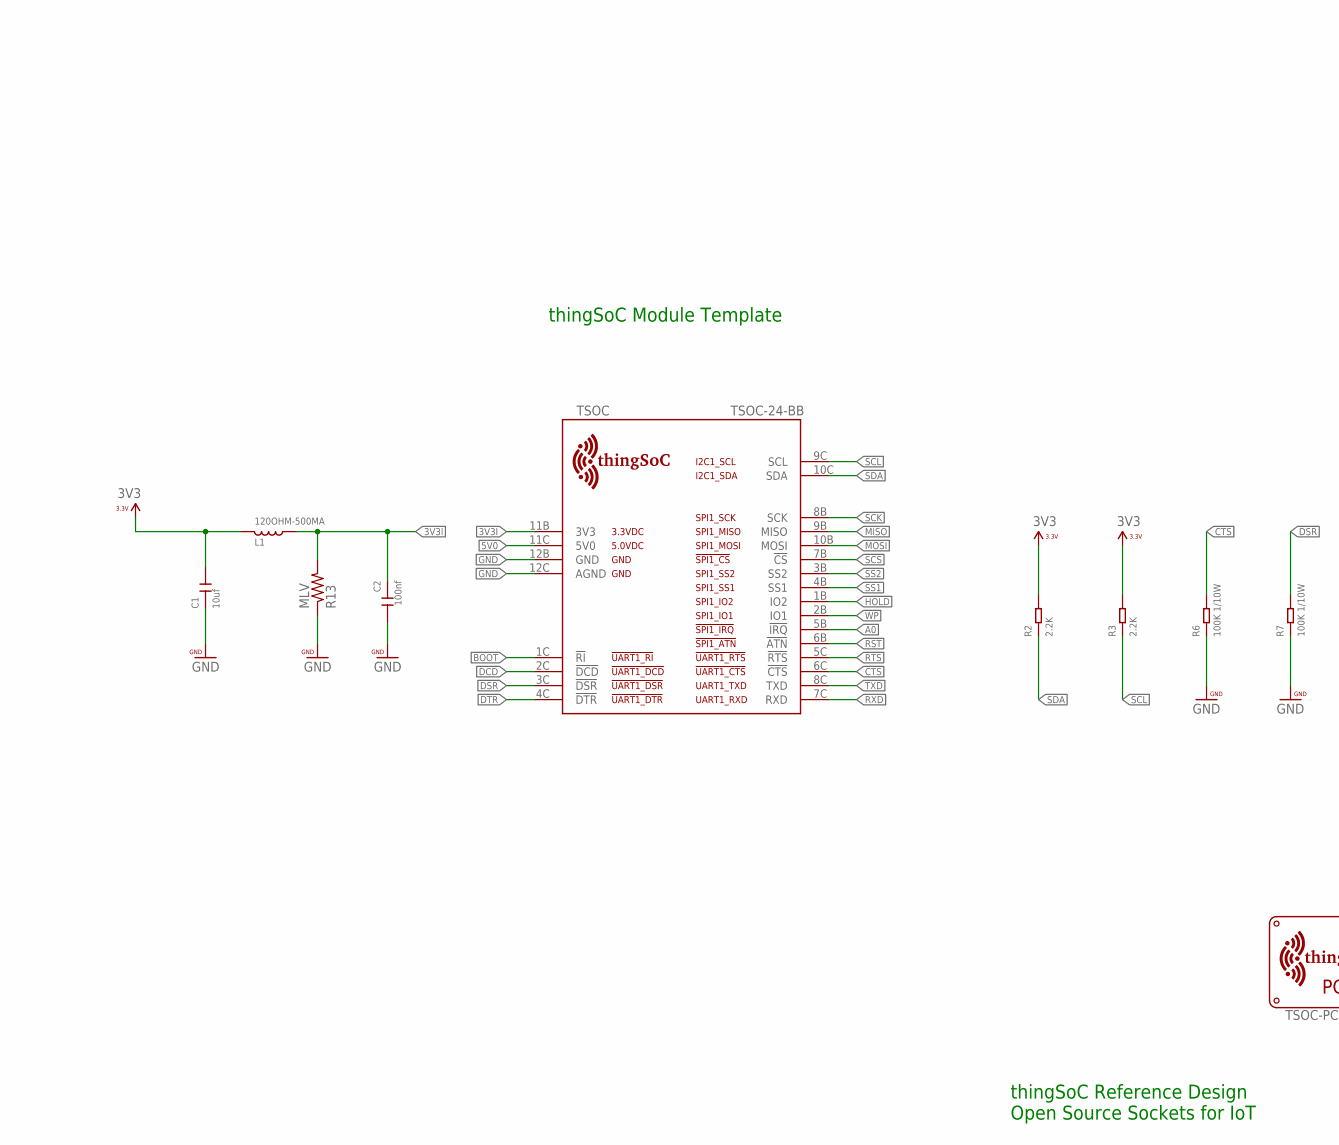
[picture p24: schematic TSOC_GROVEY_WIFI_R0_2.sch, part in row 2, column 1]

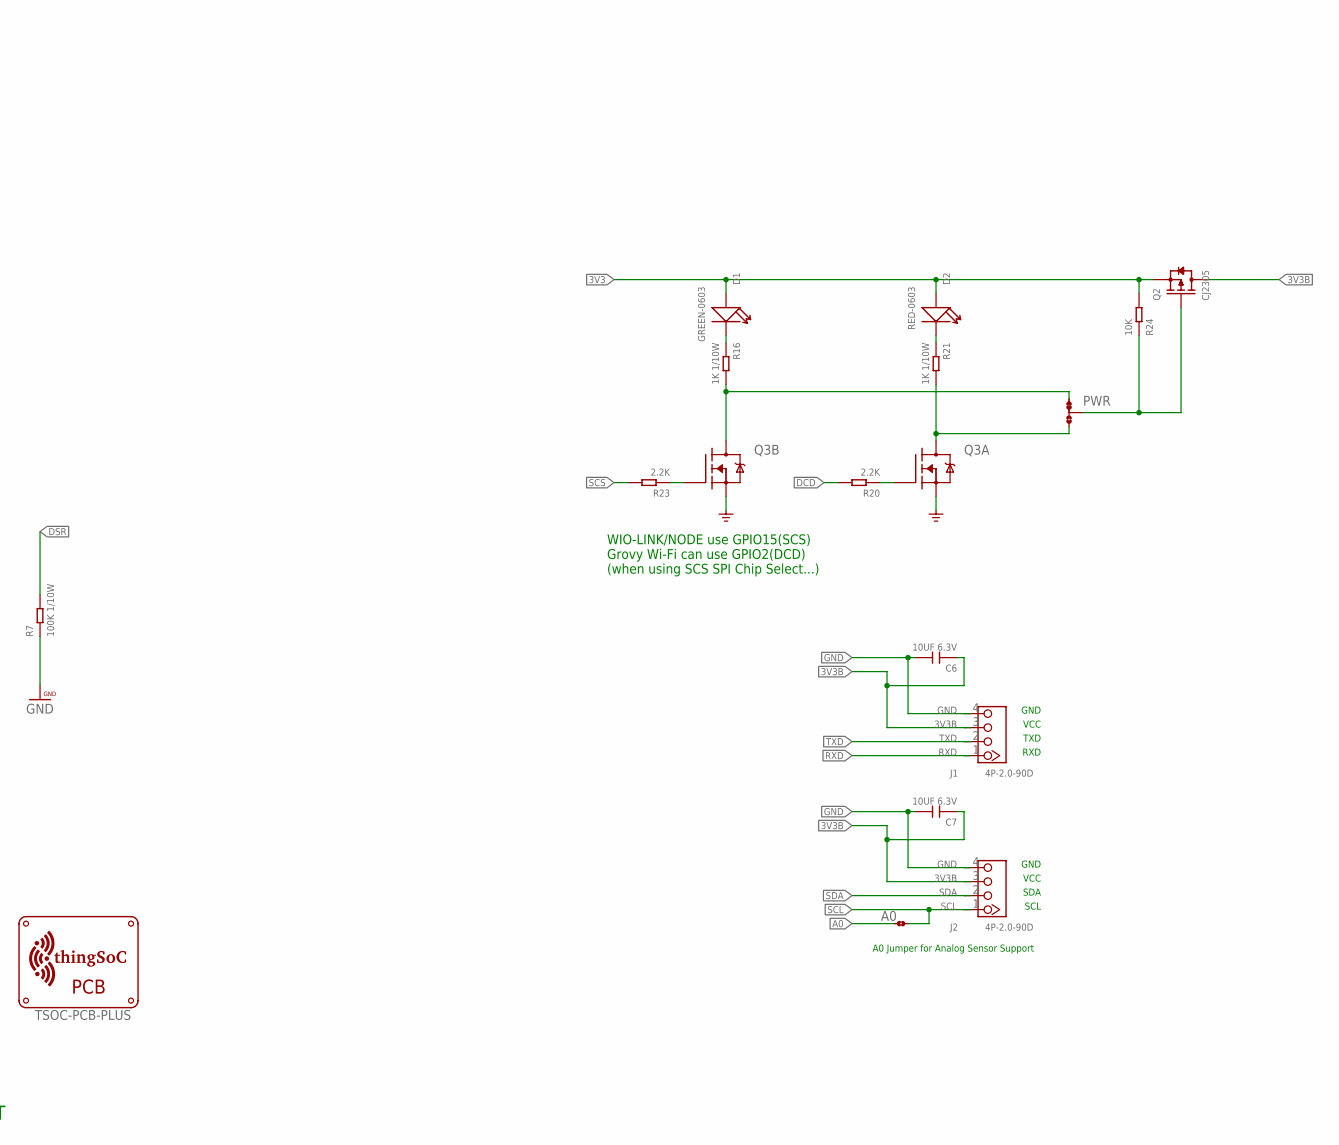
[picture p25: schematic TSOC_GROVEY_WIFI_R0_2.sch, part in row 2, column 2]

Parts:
A0: JMP-2-NO
AR: JMP-3-1_2
BOOT: SMD-SWITCH-TACTILE-SPST-NO(4P-D6.0MM); SW4-SMD-6.0X6.0X5.0MM
C1, C5: 10uf; C1206
C2, C3, C4: 100nf; C0603
C6, C7: 10UF 6.3V; C0603
D1: GREEN-0603; LED-0603
D2: RED-0603; LED-0603
J1, J2: 4P-2.0-90D; HW4-2.0-90D
L1: 120OHM-500MA; L0603
PCB: TSOC-PCB-PLUS; TSOC-BB-BRD-PLUS-DIM
PWR: JMP-3-1_2
Q1: MMBT2222A; SOT363
Q2: CJ2305; SOT-23
Q3: FDG1024NZ; SOT95P280X110-6N
R1, R4, R5, R9, R10, R12, R14, R24: 10K; R0603
R2, R3, R20, R23: 2.2K; R0603
R6, R7: 100K 1/10W; R0603
R8, R11, R19: 100K; R0603
R13: MLV; 0402-RES
R16, R17, R18, R21: 1K 1/10W; R0603
RESET: SMD-SWITCH-TACTILE-SPST-NO(4P-D6.0MM); SW4-SMD-6.0X6.0X5.0MM
TSOC: TSOC-24-BB; TSOC-BB-S24
U1: ESP12ESMD; ESP12E-SMD
U2: EEPROM-I2CSMD; SO08
U3: S25FL016K0XMFI041; SOIC127P600X175-8N

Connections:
3V3: AR.1, C1.2, C3.2, C4.2, C5.2, D1.+, D2.+, L1.1, Q2.2 (S), R1.2, R2.2, R3.2, R5.2, R12.2, R24.2, U1.VCC, U2.8 (VCC), U3.8 (VCC)
3V3B: C6.1, C7.1, J1.3, J2.3, Q2.3 (D)
3V3I: C2.1, L1.2, R13.2, TSOC.11B (3V3)
5V0: TSOC.11C (5V0)
!BOOT: BOOT.1 (A0), BOOT.2 (B0), Q1.6 (C), R5.1, TSOC.1C (!RI), U1.GPIO0
!BOOTPD: BOOT.3 (B1), BOOT.4 (A1), R18.2
!CTS: R6.2, TSOC.6C (!CTS)
!DCD: R20.2, TSOC.2C (!DCD), U1.GPIO2
!DSR: R7.2, TSOC.3C (!DSR)
!DTR: Q1.1 (E), R9.1, TSOC.4C (!DTR)
!HCS: U1.CS0
!HOLD: TSOC.1B (IO2), U3.7 (HOLD_(IO3))
!RST: Q1.3 (C), R1.1, R14.1, RESET.1 (A0), RESET.2 (B0), TSOC.6B (!ATN), U1.RESET
!RSTPD: R17.2, RESET.3 (B1), RESET.4 (A1)
!RTS: Q1.4 (E), R10.1, TSOC.5C (!RTS)
!SCS: R4.2, R23.2, TSOC.7B (!CS), U1.GPIO15, U3.1 (CS)
!WP: TSOC.2B (IO1), U3.3 (WP_(IO2))
A0: A0.2, R8.1, TSOC.5B (!IRQ)
ADC: R11.1, R19.2, U1.ADC
ADC2: R8.2, R19.1
CH_PD: R12.1, U1.CH_PD
G0: PWR.3, Q3.6 (D), R21.2
G15: PWR.1, Q3.3 (D), R16.2
GND: AR.3, C1.1, C2.2, C3.1, C4.1, C5.1, C6.2, C7.2, J1.4, J2.4, Q3.1 (S), Q3.4 (S), R4.1, R6.1, R7.1, R11.2, R13.1, R17.1, R18.1, TSOC.12B (GND), TSOC.12C (AGND), U1.GND, U2.4 (VSS), U2.7 (WP), U3.4 (GND)
GROVEPWR: PWR.2, Q2.1 (G), R24.1
HMISO: U1.MISO
HMOSI: U1.MOSI
HSCK: U1.SCLK
LED1: D1.-, R16.1
LED2: D2.-, R21.1
MISO: TSOC.9B (MISO), U1.GPIO12, U3.2 (SO_(IO1))
MOSI: TSOC.10B (MOSI), U1.GPIO13, U3.5 (SI_(IO0))
unnamed: AR.2, U2.1 (A0), U2.2 (A1), U2.3 (A2)
unnamed: Q1.5 (B), R9.2
unnamed: Q3.2 (G), R20.1
unnamed: Q3.5 (G), R23.1
unnamed: Q1.2 (B), R10.2
RXD: J1.1, TSOC.7C (RXD), U1.TXD0 (TX)
SCK: TSOC.8B (SCK), U1.GPIO14, U3.6 (CLK)
SCL: A0.1, J2.1, R3.1, TSOC.9C (SCL), U1.GPIO5, U2.6 (SCL)
SDA: J2.2, R2.1, TSOC.10C (SDA), U1.GPIO4, U2.5 (SDA)
SS1: TSOC.4B (SS1), U1.GPIO9 (*GPIO9)
SS2: TSOC.3B (SS2), U1.GPIO10 (*GPIO10)
TXD: J1.2, TSOC.8C (TXD), U1.RXD0 (RX)
WAKE: R14.2, U1.GPIO16

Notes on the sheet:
thingSoC Reference Design Open Source Sockets for IoT
thingSoC Module Template
Normal Booting -------------- CH_PD (High) GPIO0 (High) GPIO2 (High) GPIO15 (Low)
ESP8266- Model-07 WiFi Module
Flash Programming & Reset Modes --------------------------------------------- | nDTR | nRTS | nRST | GPIO0 | --------------------------------------------- | 0 | 0 | 1 | 1 | | 0 | 1 | 1 | 0 | | 1 | 0 | 0 | 1 | | 1 | 1 | 1 | 1 | ---------------------------------------------
NVSRAM FM24V10 (128K x 8 bits SRAM)
GND
VCC
TXD
RXD
SDA
SCL
A0 Jumper for Analog Sensor Support
WIO-LINK/NODE use GPIO15(SCS) Grovy Wi-Fi can use GPIO2(DCD) (when using SCS SPI Chip Select...)
NB: The 1K Resistor is used to protect the BOOT (GPIO0) pin when it is acting as an output pin. (the push button shorts it to ground!)
NB: The pull down resistor is used to make sure the SCS (GPIO15) is low during Reset (Boot Mode).

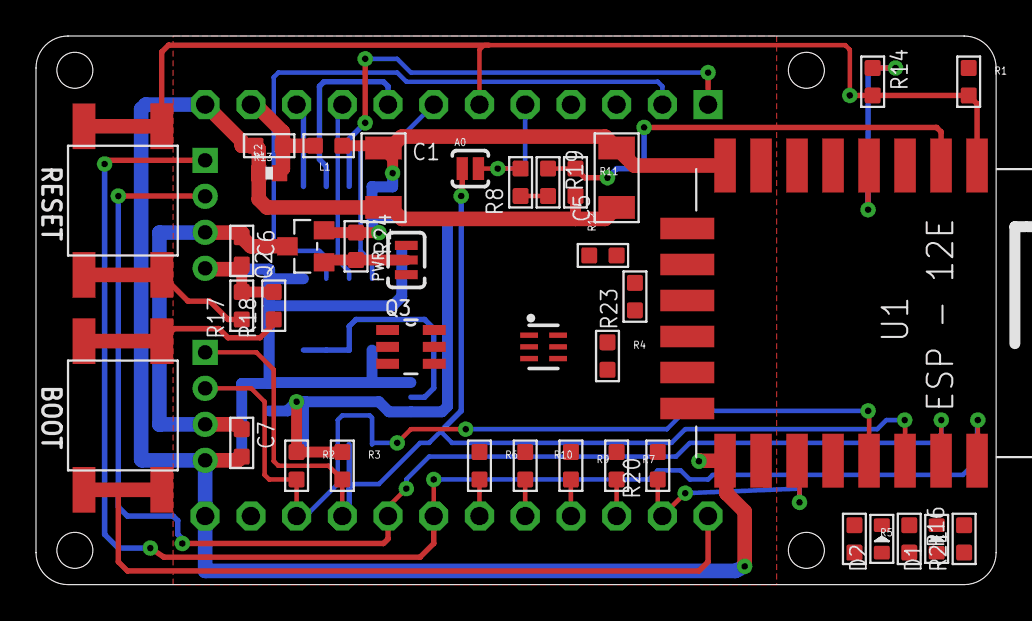
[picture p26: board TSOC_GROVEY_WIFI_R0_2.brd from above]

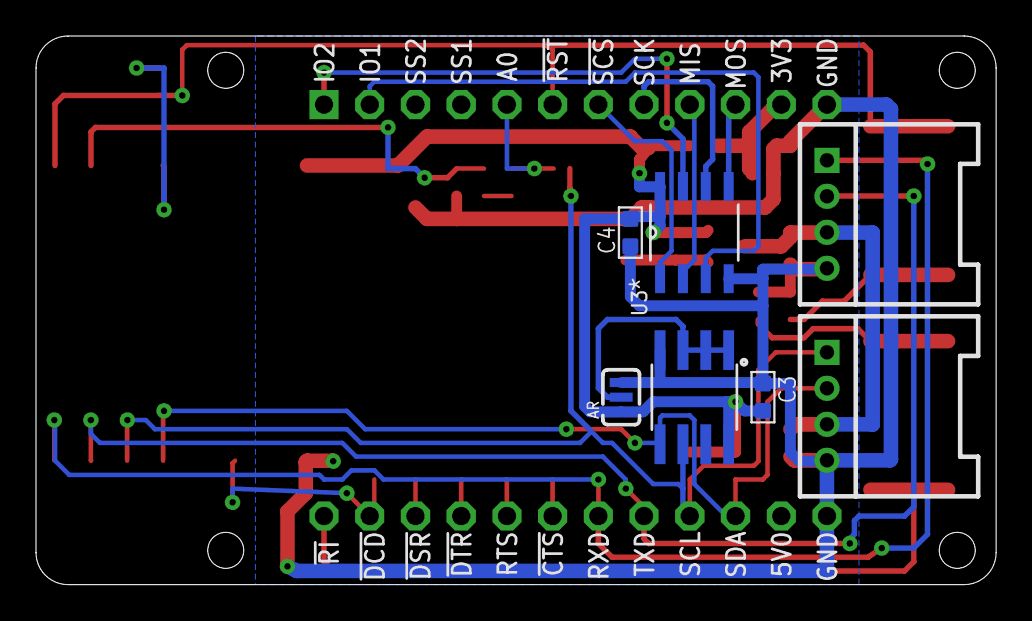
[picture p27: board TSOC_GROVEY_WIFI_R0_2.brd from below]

Board: 2 copper layers, 53.3 x 30.5 mm, 47 parts (7 on the bottom side), 40 nets.

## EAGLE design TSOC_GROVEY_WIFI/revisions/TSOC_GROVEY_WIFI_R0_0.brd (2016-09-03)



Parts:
C1: 1.0uF; 0402-CAP
C2, C3: 0.1uF; 0402-CAP
JP1: JMP-2-NO-0402
LED1: LED-TRICOLOR; LED-TRICOLOR-SMD
Q1: MMBT2222A; SOT363
R1, R4, R5, R6, R7, R8, R9, R10, R12, R13: 10K; 0402-RES
R2, R3, R14: 4K7; 0402-RES
R11: 4K2; 0402-RES
R15: 0.01; 0402-RES
R16, R17, R18: 560; 0402-RES
TSOC: TSOC-24-BB; TSOC-BB-S24
U1: ESP8266-12-12W; ESP8266-12W
U2: EEPROM-I2CSMD; SO08
U3: TMP102; SOT563
U$19, U$20: TSOC-LOGO-MED
U$25: TSOC-PCB-PLUS; TSOC-BB-BRD-PLUS-DIM

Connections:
3V3: C3.2, JP1.1, LED1.A, R1.2, R2.2, R3.2, R5.2, R12.2, R13.2, R15.1, U1.3V3, U2.1 (A0), U2.2 (A1), U2.3 (A2), U2.8 (VCC), U3.5 (VCC)
3V3I: C1.1, C2.1, R15.2, TSOC.11B (3V3)
!CTS: R6.2, TSOC.6C (!CTS)
!DCD: TSOC.2C (!DCD)
!DSR: R7.2, TSOC.3C (!DSR)
!DTR: Q1.1 (E), R9.1, TSOC.4C (!DTR)
!RI: TSOC.1C (!RI)
!RST: Q1.3 (C), R1.1, R14.2, U1.!RST
!RTS: Q1.4 (E), R10.1, TSOC.5C (!RTS)
ADC: R8.1, R11.1, U1.ADC
ADC_RAW: JP1.2, R8.2
BLU: LED1.B (BLU), R16.2
CH_PD: R12.1, U1.CH_PD
GND: C1.2, C2.2, C3.1, R4.1, R6.1, R7.1, R11.2, TSOC.12B (GND), TSOC.12C (AGND), U1.GND, U2.4 (VSS), U2.7 (WP), U3.2 (GND), U3.4 (ADD0)
GPIO0: Q1.6 (C), R5.1, R18.1, TSOC.3B (SS2), U1.G0
GPIO1: TSOC.7C (RXD), U1.G1
GPIO2: TSOC.4B (SS1), U1.G2
GPIO3: TSOC.8C (TXD), U1.G3
GPIO4: R2.1, R16.1, TSOC.10C (SDA), U1.G4, U2.5 (SDA), U3.6 (SDA)
GPIO5: R3.1, R17.1, TSOC.9C (SCL), U1.G5, U2.6 (SCL), U3.1 (SCL)
GPIO12: TSOC.9B (MISO), U1.G12
GPIO13: TSOC.10B (MOSI), U1.G13
GPIO14: TSOC.8B (SCK), U1.G14
GPIO15: R4.2, TSOC.7B (!CS), U1.G15
GPIO16: R13.1, R14.1, TSOC.2B (IO1), U1.G16
GRN: LED1.G (GRN), R17.2
unnamed: Q1.5 (B), R9.2
unnamed: Q1.2 (B), R10.2
RED: LED1.R (RED), R18.2

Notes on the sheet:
thingSoC Reference Design Open Source Sockets for IoT
thingSoC Module Template
Normal Booting -------------- CH_PD (High) GPIO0 (High) GPIO2 (High) GPIO15 (Low)
ESP8266- Model-07 WiFi Module
Flash Programming & Reset Modes --------------------------------------------- | nDTR | nRTS | nRST | GPIO0 | --------------------------------------------- | 0 | 0 | 1 | 1 | | 0 | 1 | 1 | 0 | | 1 | 0 | 0 | 1 | | 1 | 1 | 1 | 1 | ---------------------------------------------
NOTE: 1) Connect JP1 for Volts or Temp. Measurement 2) R8 is 10K resistor for Volt Measurement 3) R8 is 10K Thermistor for Temp, Measurement 4) Connect External Sensor to JP1-Pin2
NVSRAM FM24V10 (128K x 8 bits SRAM)
I2C Temp Sensor



Board: 2 copper layers, 53.3 x 30.5 mm, 31 parts (4 on the bottom side), 27 nets.

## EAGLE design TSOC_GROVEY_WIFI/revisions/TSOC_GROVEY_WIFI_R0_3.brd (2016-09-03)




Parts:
C1, C2, C6: 10uf; C1206
C3: 470nF; 0402-CAP
C4, C5: 100nf; C0603
D1: GREEN-0603; LED-0603
D2: RED-0603; LED-0603
D4, D5: 20V-1A; SOD-123
J1P: M02-JST-2-PTH-NO_SILK; JST-2-PTH-NS
L1: 120OHM-500MA; L0603
PCB: TSOC-PCB-PLUS; TSOC-BB-BRD-PLUS-DIM
Q1: MMBT2222A; SOT363
Q3: FDG1024NZ; SOT95P280X110-6N
R1, R4, R5, R9, R10, R12, R14: 10K; R0603
R2, R3, R20, R23: 2.2K; R0603
R6, R7: 100K 1/10W; R0603
R8, R11, R19: 100K; R0603
R16, R17, R18, R21: 1K 1/10W; R0603
SW1, SW2: DHT-4235A; SW4-SMD-4.2X3.2X2.5MM
TSOC: TSOC-24-BB; TSOC-BB-S24
U1: ESP12ESMD; ESP12E-SMD
U2: MIC5219 3.3V; SOT23-5

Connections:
3V3: C2.2, C4.2, C5.2, C6.2, D1.+, D2.+, L1.1, R1.2, R2.2, R3.2, R5.2, R12.2, U1.VCC, U2.5 (OUT)
3V3I: L1.2, TSOC.11B (3V3)
5V0: D4.+, TSOC.11C (5V0)
!BOOTPD: R18.2, SW2.2 (A1), SW2.4 (B1)
!CTS: R6.2, TSOC.6C (!CTS)
!DCDG: Q3.2 (G), R20.1
!DSR: R7.2, TSOC.3C (!DSR)
!DTR: Q1.1 (E), R9.1, TSOC.4C (!DTR)
!HCS: U1.CS0
!RST: Q1.3 (C), R1.1, R14.1, SW1.1 (A0), SW1.3 (B0), TSOC.6B (!ATN), U1.RESET
!RSTPD: R17.2, SW1.2 (A1), SW1.4 (B1)
!RTS: Q1.4 (E), R10.1, TSOC.5C (!RTS)
!SCSG: Q3.5 (G), R23.1
A0: R8.1, TSOC.5B (!IRQ)
ADC: R11.1, R19.2, U1.ADC
ADC2: R8.2, R19.1
BYPASS1: C3.1, U2.4 (BP)
CH_PD: R12.1, U1.CH_PD
G0: Q3.6 (D), R21.2
G15: Q3.3 (D), R16.2
GND: C1.1, C2.1, C3.2, C4.1, C5.1, C6.1, J1P.2, Q3.1 (S), Q3.4 (S), R4.1, R6.1, R7.1, R11.2, R17.1, R18.1, TSOC.12B (GND), TSOC.12C (AGND), U1.GND, U2.2 (GND)
GPIO0: Q1.6 (C), R5.1, SW2.1 (A0), SW2.3 (B0), U1.GPIO0
GPIO2: U1.GPIO2
GPIO4: R2.1, TSOC.10C (SDA), U1.GPIO4
GPIO5: R3.1, TSOC.9C (SCL), U1.GPIO5
GPIO9: U1.GPIO9 (*GPIO9)
GPIO10: U1.GPIO10 (*GPIO10)
GPIO12: TSOC.9B (MISO), U1.GPIO12
GPIO13: TSOC.10B (MOSI), U1.GPIO13
GPIO14: R23.2, TSOC.8B (SCK), U1.GPIO14
GPIO15: R4.2, R20.2, TSOC.7B (!CS), U1.GPIO15
GPIO16: R14.2, U1.GPIO16
HMISO: U1.MISO
HMOSI: U1.MOSI
HSCK: U1.SCLK
LED1: D1.-, R16.1
LED2: D2.-, R21.1
RES: Q1.5 (B), R9.2
ROS: Q1.2 (B), R10.2
RXD: TSOC.7C (RXD), U1.TXD0 (TX)
TXD: TSOC.8C (TXD), U1.RXD0 (RX)
VBAT: D5.+, J1P.1
VIN: C1.2, D4.-, D5.-, U2.1 (IN), U2.3 (EN)

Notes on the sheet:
thingSoC Reference Design Open Source Sockets for IoT
thingSoC Module Template
Normal Booting -------------- CH_PD (High) GPIO0 (High) GPIO2 (High) GPIO15 (Low)
ESP8266- Model-07 WiFi Module
Flash Programming & Reset Modes --------------------------------------------- | nDTR | nRTS | nRST | GPIO0 | --------------------------------------------- | 0 | 0 | 1 | 1 | | 0 | 1 | 1 | 0 | | 1 | 0 | 0 | 1 | | 1 | 1 | 1 | 1 | ---------------------------------------------
NB: The 1K Resistor is used to protect the BOOT (GPIO0) pin when it is acting as an output pin. (the push button shorts it to ground!)
NB: The pull down resistor is used to make sure the SCS (GPIO15) is low during Reset (Boot Mode).
PTH JST
3.3V LDO/Regulator


Board: 2 copper layers, 53.3 x 30.5 mm, 40 parts (0 on the bottom side), 36 nets.

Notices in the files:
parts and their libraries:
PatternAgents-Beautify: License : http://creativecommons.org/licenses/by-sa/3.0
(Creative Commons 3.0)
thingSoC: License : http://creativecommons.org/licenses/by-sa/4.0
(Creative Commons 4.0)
